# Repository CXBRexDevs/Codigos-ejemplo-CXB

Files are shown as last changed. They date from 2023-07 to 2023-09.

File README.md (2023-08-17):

# CXB Rex

Es una plataforma de desarrollo orientada hacia control avanzado de variables físicas, que integra drivers de motores, interfaces de comunicación y acoplo de sensores,  con el fin de facilitar experimentos para el desarrollo academico superior. En la siguiente [imagen](https://github.com/CXBRexDevs/Codigos-ejemplo-CXB/blob/015453cbffbb8909efc1b8809f53027d9adc56b4/images/BASEDibujoCXBareas.png) se aprecia la disposición de los periféricos disponibles al usuario. Mientras qeu las conexiones internas de la PCB se documentan en los [planos]() del proyecto.

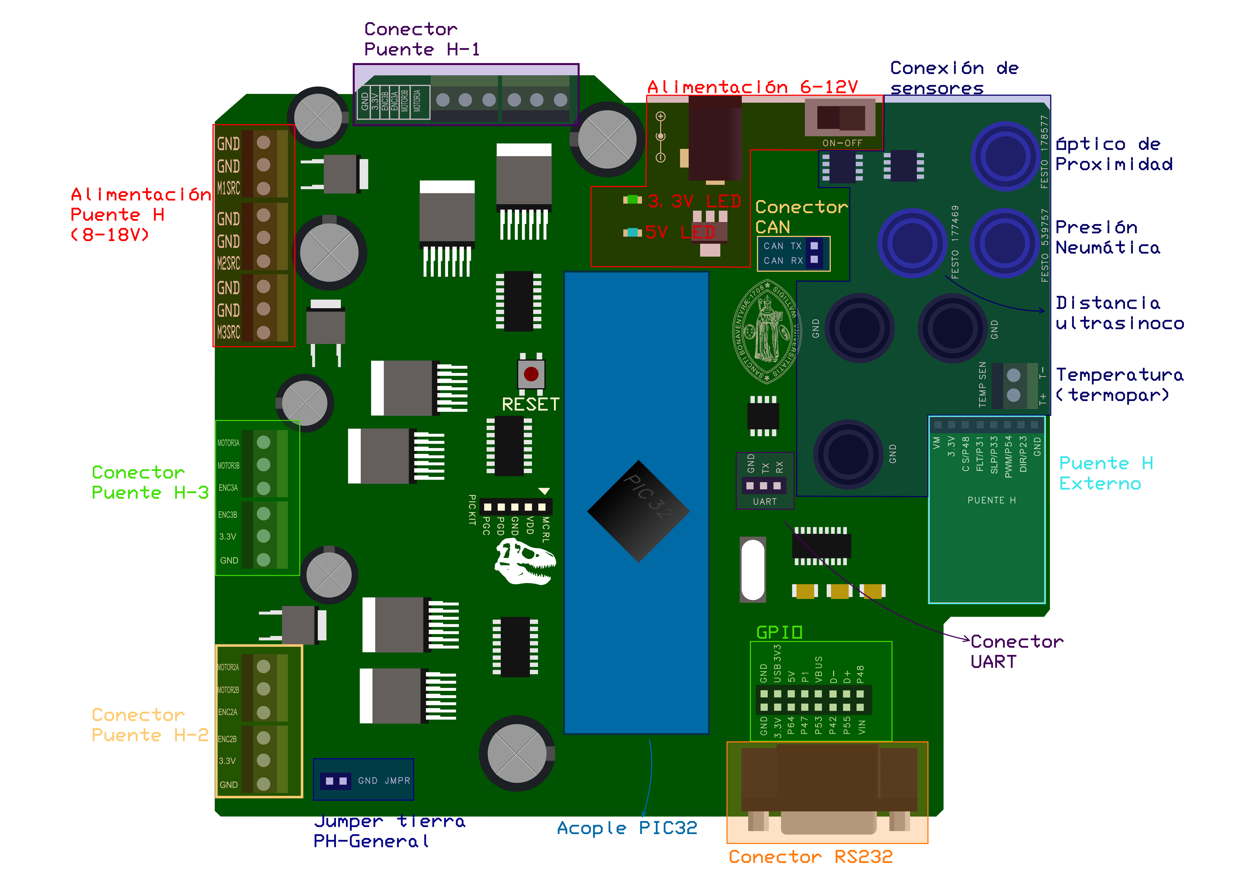
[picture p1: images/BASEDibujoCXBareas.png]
https://github.com/CXBRexDevs/Codigos-ejemplo-CXB/blob/main/images/BASEDibujoCXBareas.png?raw=true


En este repositorio se encuentran los planos y archivos de fabricación, códigos ejemplo, circuitos de prueba externos a la tarjeta electronica y entre otros archivos de interés.

# Guía de instalación programador

## *Advertencia: Pickit 3 solo es compatible con versiones de MPLAB anteriores a la versión 6.05*

## Programas necesarios

- MPLAB IDE

- Compilador XC32

- MPLAB Code Configurator
  
  ## MPLAB IDE
  
  Para la instalación de estos dos programas se debe ingresar a [MPLAB® X IDE | Microchip Technology](https://www.microchip.com/en-us/tools-resources/develop/mplab-x-ide) . Una vez en la página, seleccione la opción “Download MPLAB X IDE” y posteriormente descargue la versión de Windows.

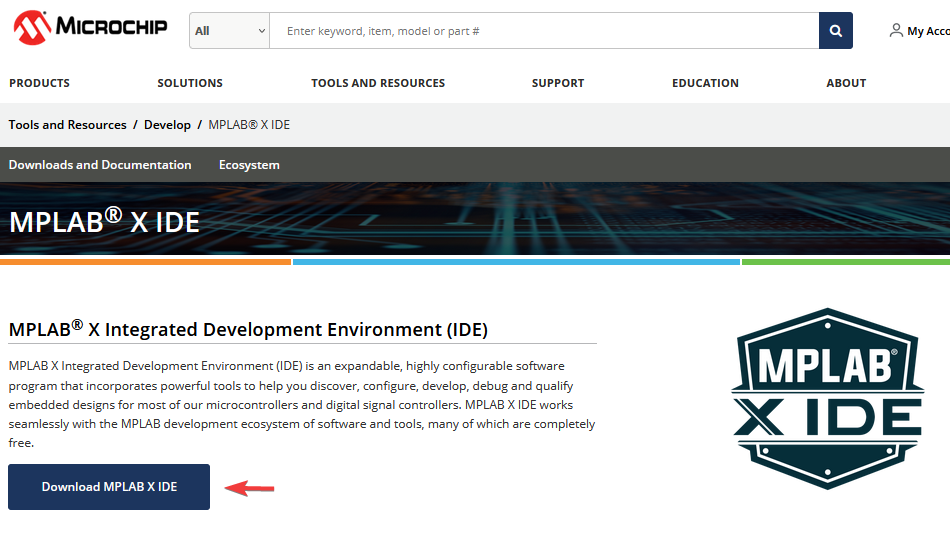
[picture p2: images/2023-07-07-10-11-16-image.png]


Puede descargar versiones anteriores navegando en la misma página al botón "Go To Downloads Archives" y buscando en el navegador su versión predilecta.

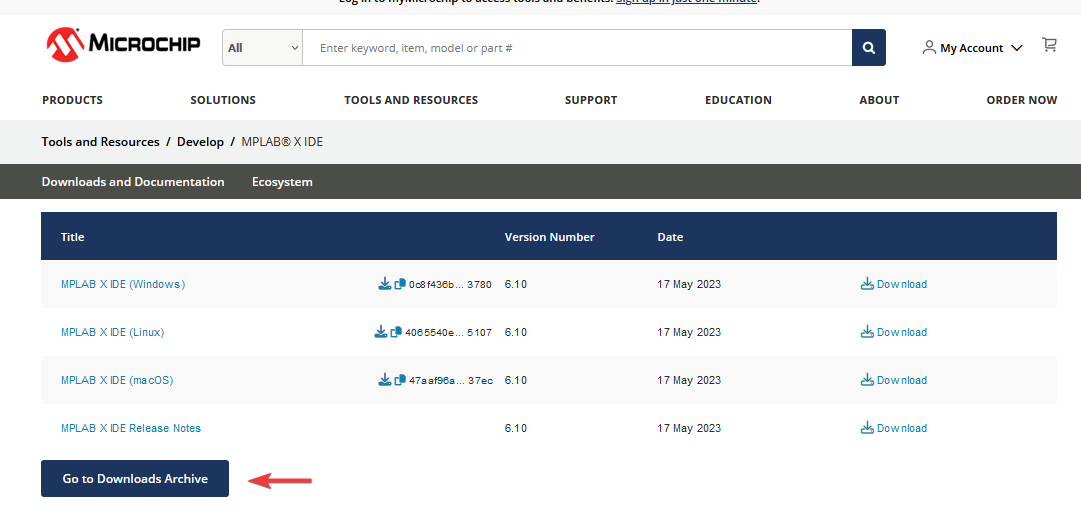
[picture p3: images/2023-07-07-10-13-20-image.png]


Una vez descargado el archivo abra el ejecutable.





Ahora debe dar clic en aceptar el acuerdo de usuario y así poder seguir el proceso de instalación haciendo clic en ‘next’.

![]([C:\Users\PEDRO\AppData\Roaming\marktext\images\2023-07-07-10-25-39-image.png](https://github.com/CXBRexDevs/Codigos-ejemplo-CXB/blob/main/images/2023-07-07-10-25-39-image.png?raw=true)https://github.com/CXBRexDevs/Codigos-ejemplo-CXB/blob/main/images/2023-07-07-10-25-39-image.png?raw=true)

Escoja el directorio donde desea instalar MPLAB X IDE y pulse siguiente.

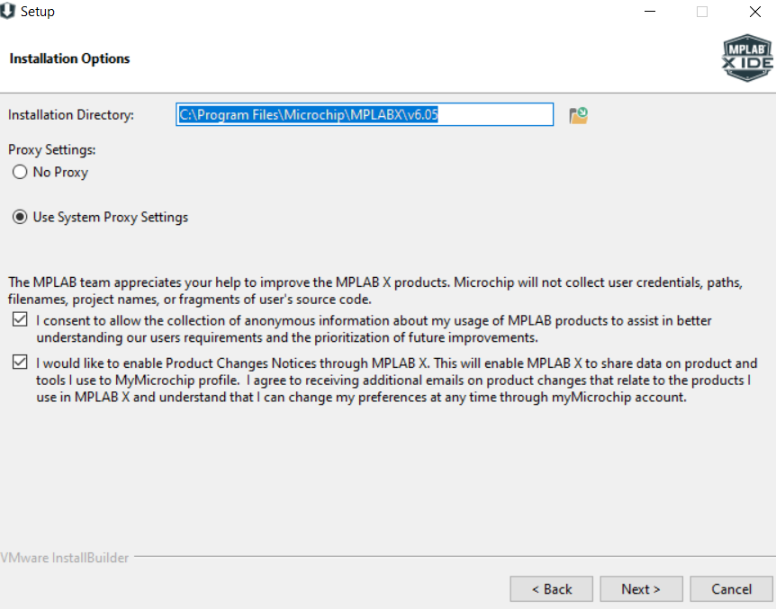
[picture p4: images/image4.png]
Modificar la ruta por defeco de instalación es opcional.


Ahora el instalador preguntará cuáles programas desea instalar, se recomienda la instalación de todos los aplicativos de la imagen abajo, pero para el uso de CXB-REX, solo es necesario “MPLAB X IDE” y “32 bit MCUs”.

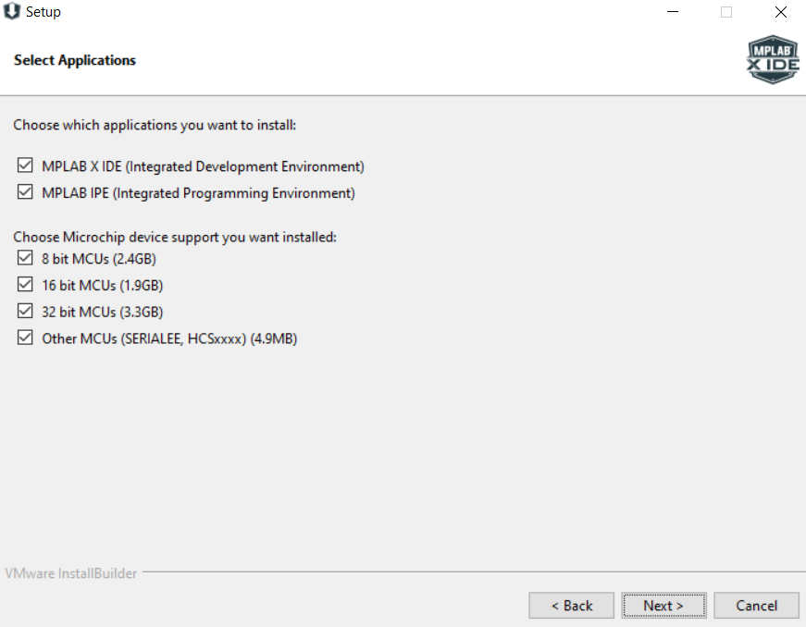
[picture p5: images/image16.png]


Al hacer clic en siguiente se iniciará la instalación.

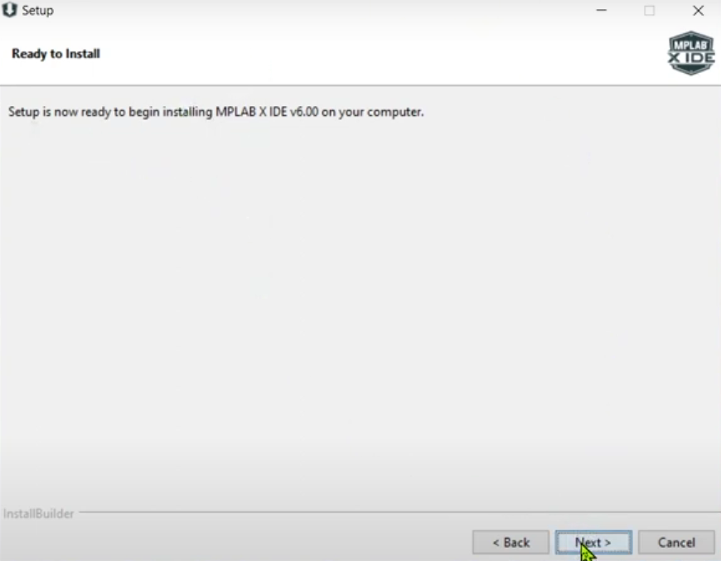
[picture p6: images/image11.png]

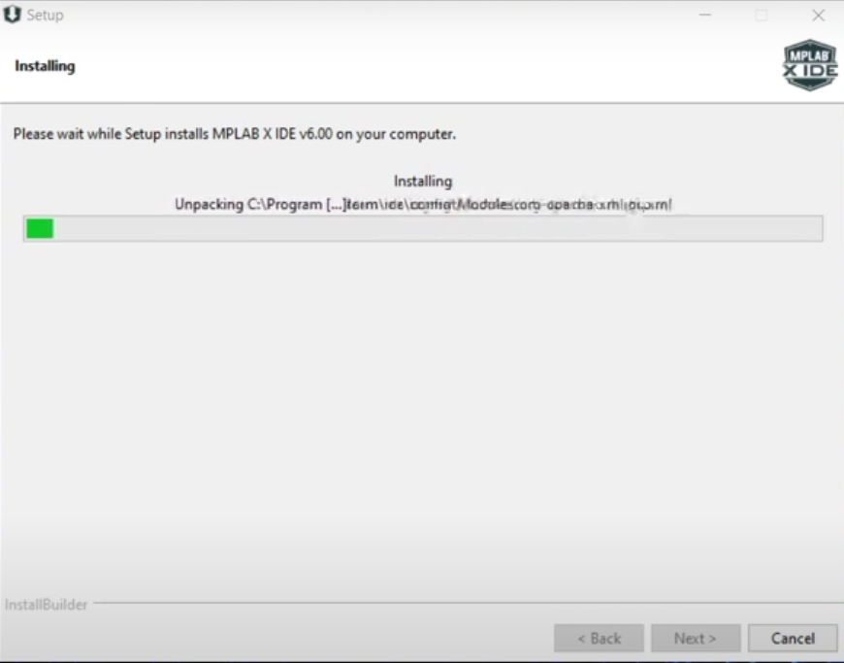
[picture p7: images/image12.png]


Espere a que termine la instalación y haga clic en finalizar una vez la opción se habilite.

## MPLAB XC32 COMPILER:

Ingrese a [MPLAB XC Compiler Downloads and Documentation | Microchip Technology](https://www.microchip.com/en-us/tools-resources/develop/mplab-xc-compilers/downloads-documentation) y seleccione la opción “XC32 Compilers” y posteriormente descargue la versión de Windows.

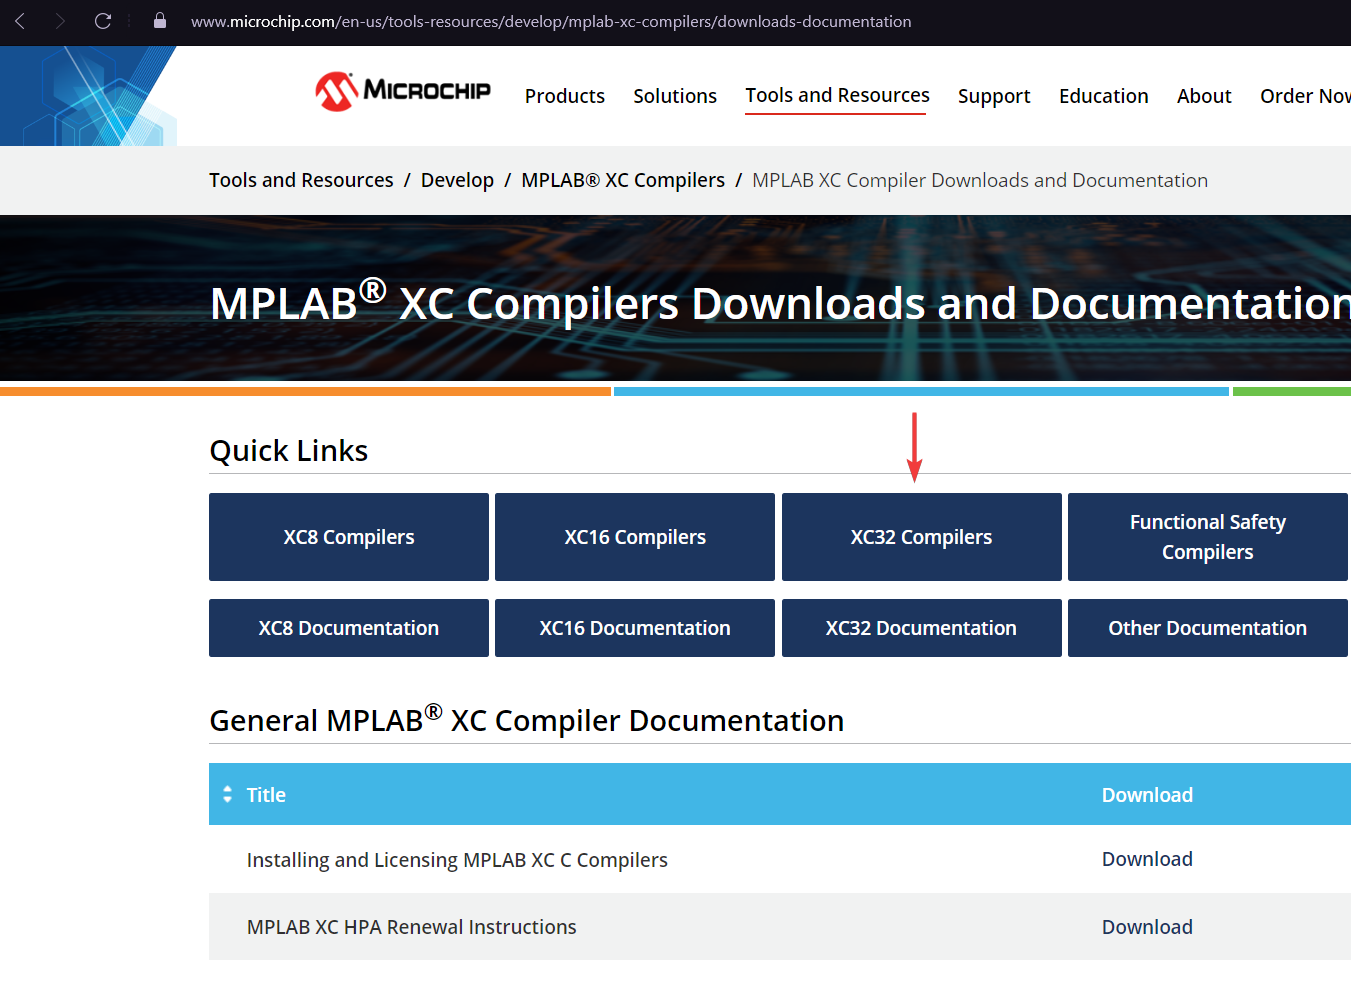
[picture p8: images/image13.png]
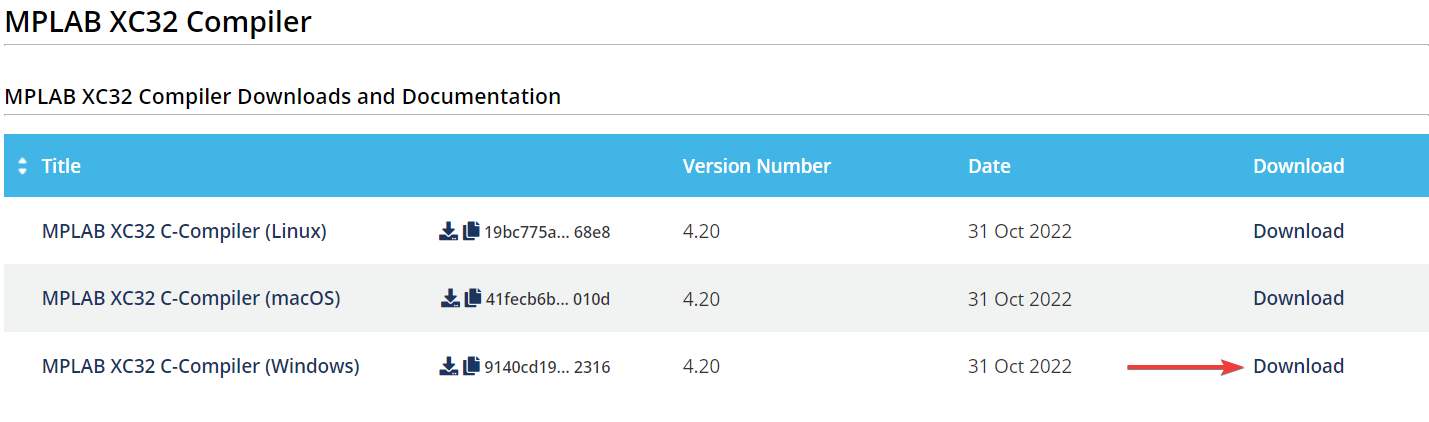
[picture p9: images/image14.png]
 

Una vez se ha descargado el instalador, ejecute la aplicación, los pasos a seguir son los mismos que para la instalación de MPLAB IDE, excepto por el tipo de licencia, en la cual debe seleccionar ‘free’.

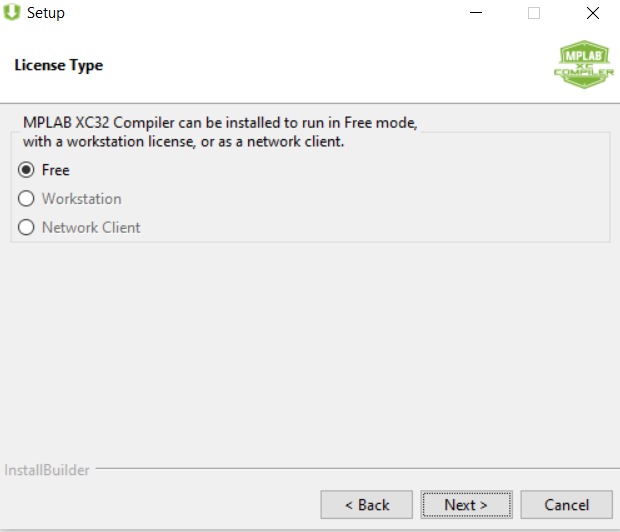
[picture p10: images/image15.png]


Después de escoger la licencia, se escoge el directorio de instalación y el programa procederá a instalarse, de la misma manera que MPLAB IDE, solo que al final dirá la información de la licencia, pero debido a que se seleccionó gratuita solo se debe dar clic en next para finalizar.

## MPLAB Harmony V3

El primer paso es abrir MPLAB IDE, luego seleccionar el apartado de "tools" en la parte superior de la pantalla, y en la ventana desplegada seleccionar "Plugins".

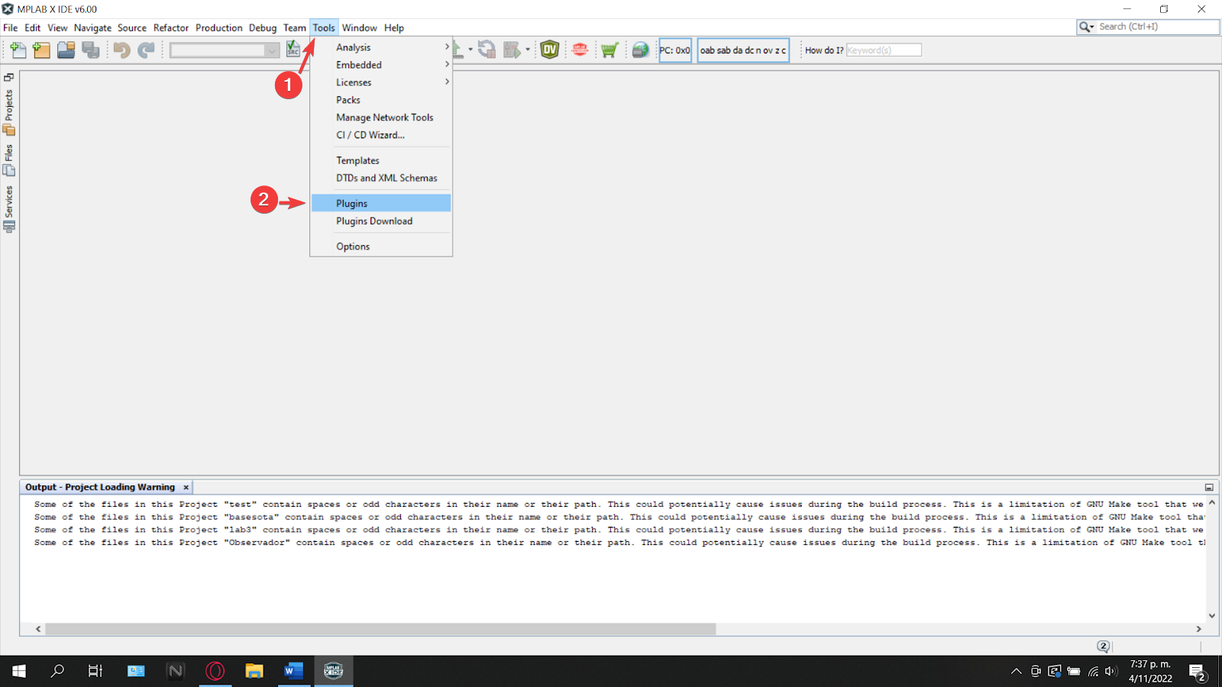
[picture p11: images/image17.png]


En la ventana de plugins seleccionar la pestaña de "Updates" y en el listado buscar si se encuentra “MPLAB@ Code Configurator”, si es el caso seleccionelo y haga clic en "Update".

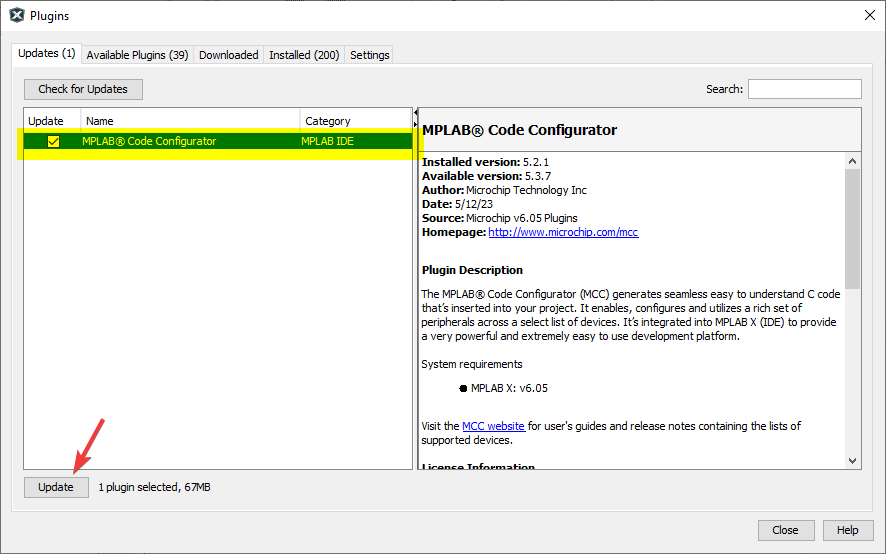
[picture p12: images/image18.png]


Aparecerá una nueva ventana dandole la bienvenida al instalador, haga clic en “Next” empezará la instalación.

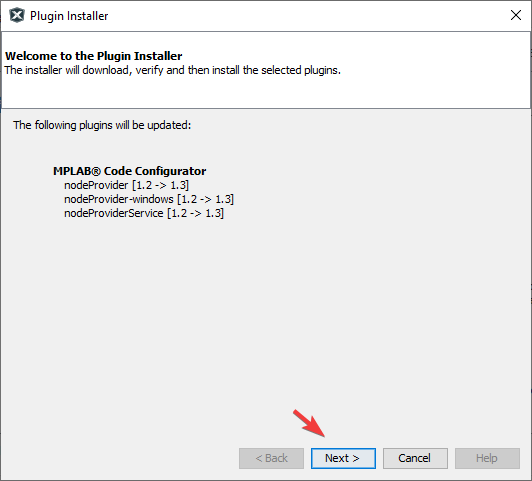
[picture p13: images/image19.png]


Luego de terminar aparecerá una ventana solicitando reiniciar MPLAB IDE para que los cambios tengan efecto, acepte y finalice.

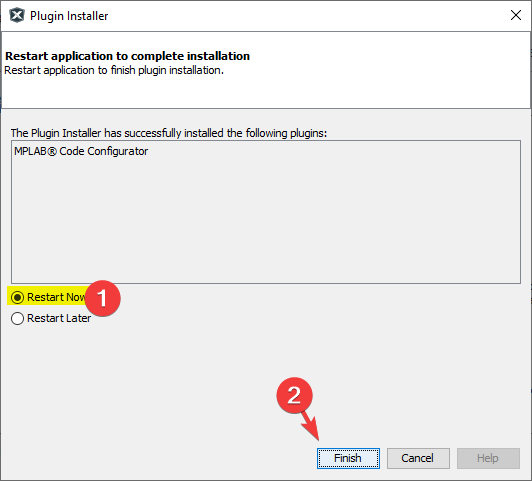
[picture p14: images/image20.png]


## Extensiones de Harmony 3:

Una vez se ha reiniciado MPLAB IDE con la instalación de harmony 3, seleccionamos en la pestaña Tools -> Embedded -> MPLAB Code Configurator v5 Open/Close

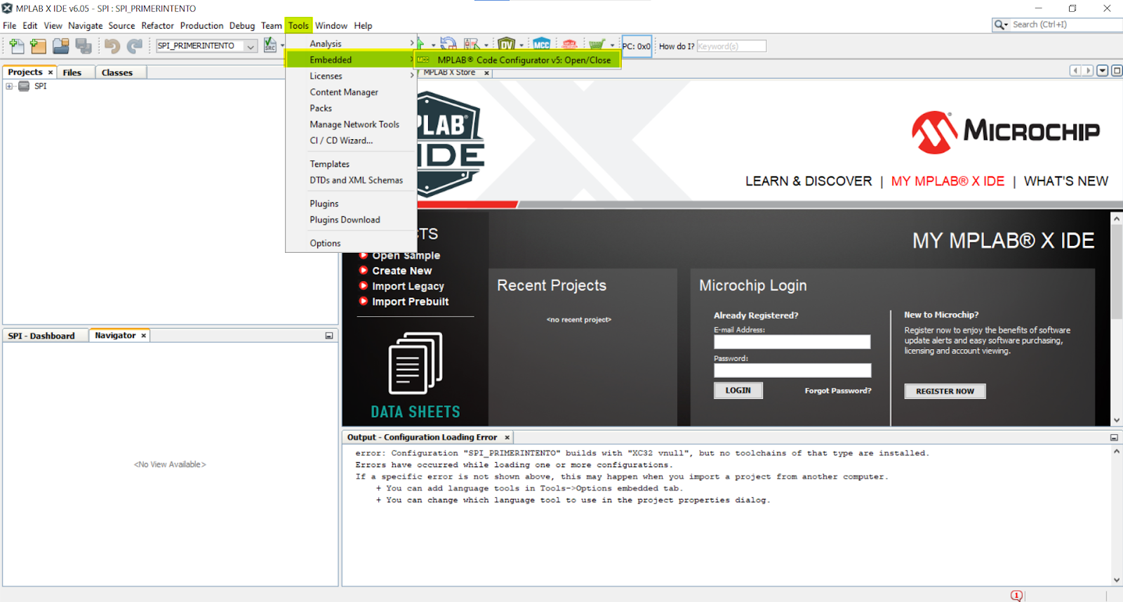
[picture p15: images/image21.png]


La primera vez que se inicia el programa mostrará un cuadro con el framework a elegir, en este caso se selecciona Harmony.

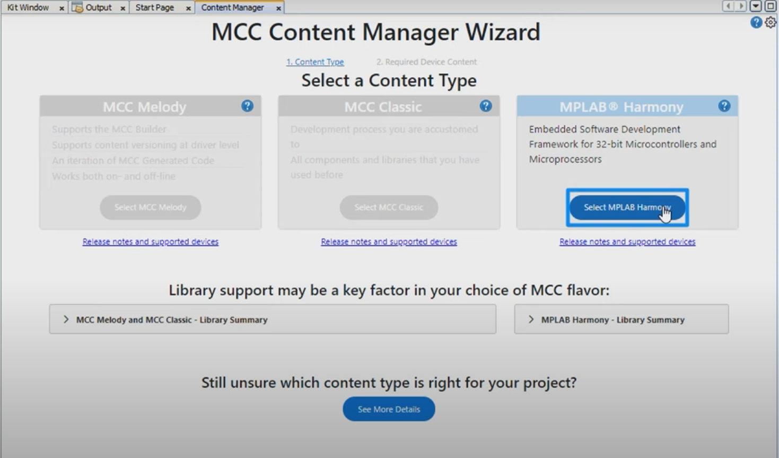
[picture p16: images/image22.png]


Una vez seleccionado aparecerá una tabla que indicara las extensiones requeridas.

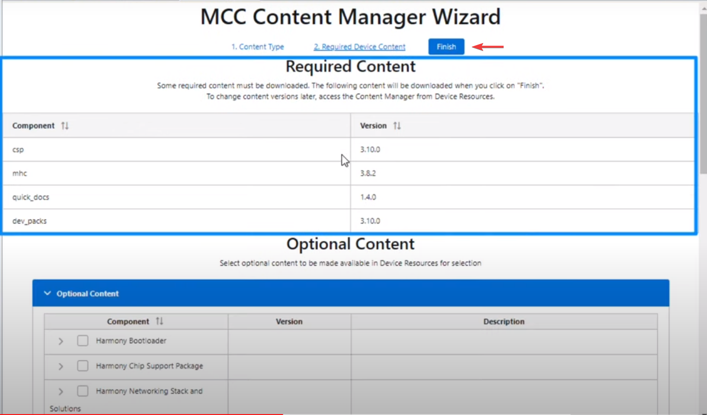
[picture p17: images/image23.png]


En caso de ser necesario también puede seleccionar las casillas del contenido opcional para que sean también se instale ese contenido, haga clic en "Finish" y espere, esto puede tomar unos minutos.  Se abrirá el siguiente entorno cuando haya terminado

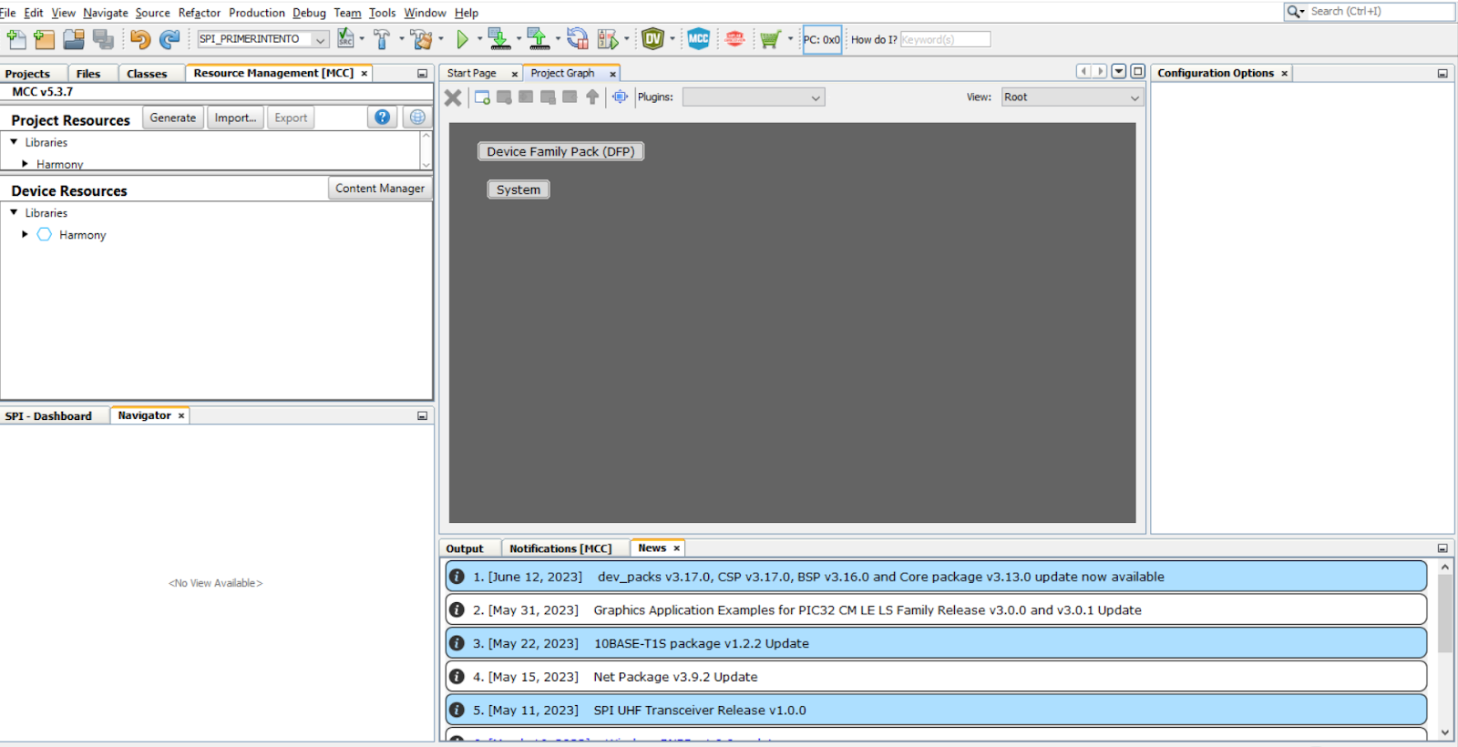
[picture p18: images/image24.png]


Ahora puede seguir la guía en "Mi primer proyecto", la cuál le guirá en este mismo proceso y le indicará como programar comunicación UART a USB o UART a RS232. También puede descargar este repositorio y abrir algún otro de los proyectos aquí descritos.

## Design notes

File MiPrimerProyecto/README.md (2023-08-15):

# Mi primer proyecto MCC HARMONY

Para empezar cualquier proyecto bajo la infraestructura de harmony v3 es necesario empezar por crear un proyecto, haga clic sobre la pestaña “File”, en la parte superior izquierda de la pantalla, luego haga clic en “New Project”. Una ventana nueva se desplegará. Seleccione la opción “32-bit MCC Harmony project”, luego pulse el botón “Next”. 

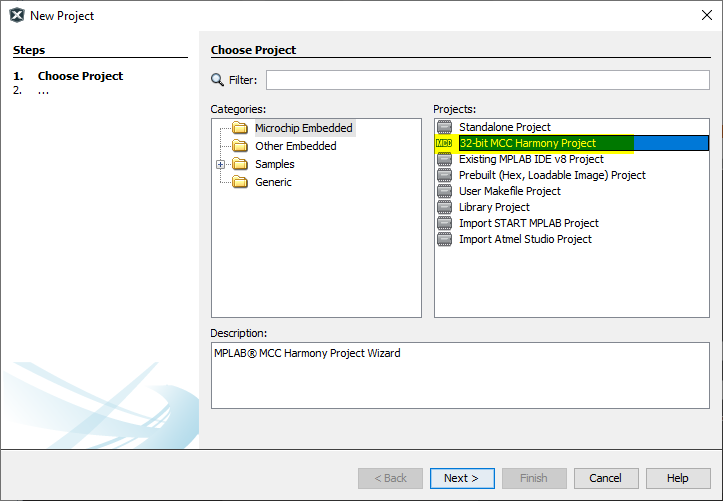
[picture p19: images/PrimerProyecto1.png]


Por defecto viene seleccionado el repositorio del cual se integra harmony 3 ([Microchip MPLAB Harmony GitHub](https://github.com/Microchip-MPLAB-Harmony/)) y la ruta donde se instalará para este proyecto (C:\Users\USUARIO\.mcc\HarmonyContent). No es necesario cambiar estas rutas, pulse el botón “Next”.

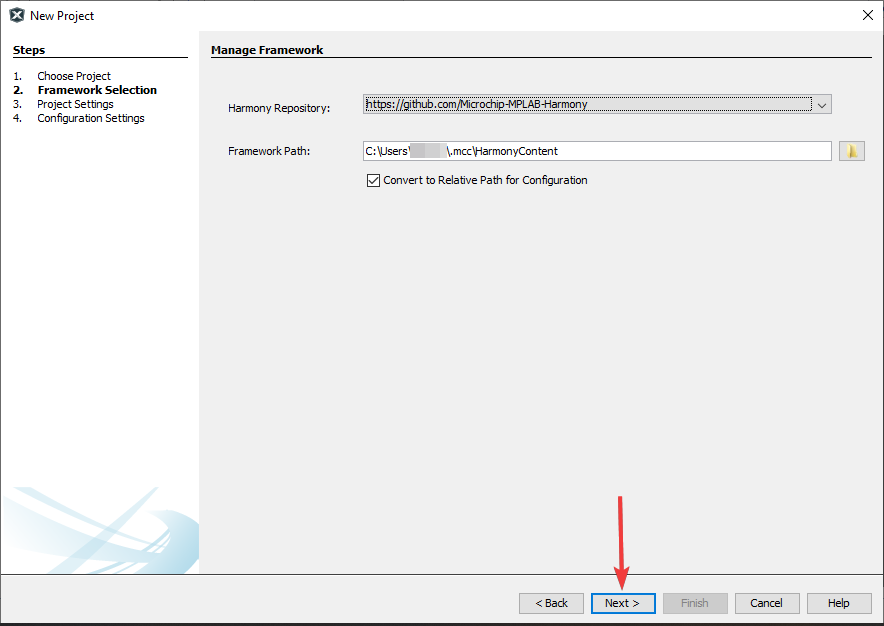
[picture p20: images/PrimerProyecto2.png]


El siguiente paso es escoger la ruta en la que se guardará su proyecto y definir su nombre, para este ejemplo, cambiaremos el nombre por defecto de la ruta a “MiPrimerProyecto” (1) y el nombre del proyecto a “HolaMundo” (2).

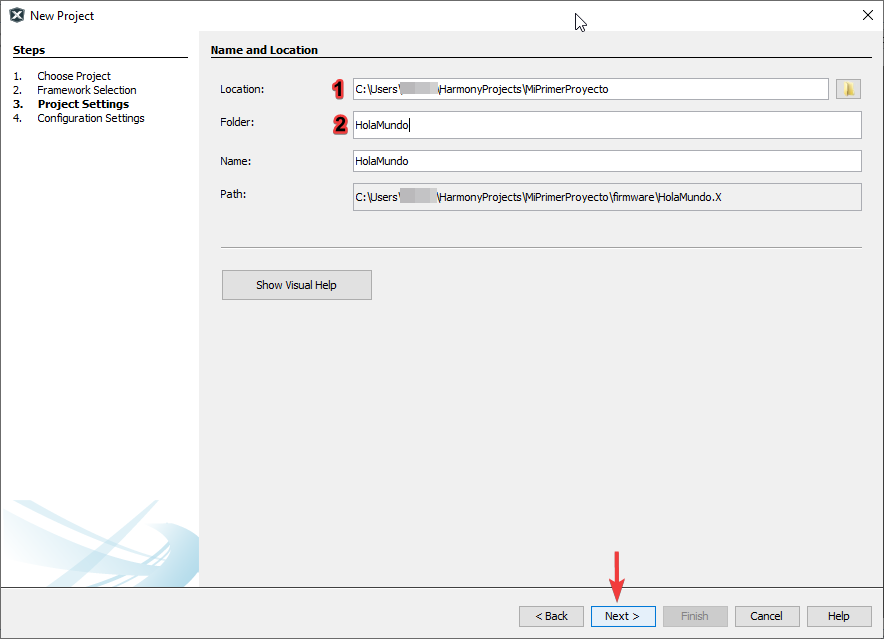
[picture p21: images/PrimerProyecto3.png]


Asegúrese de seleccionar el pic instalado en su tarjeta, CXB Rex es compatible con la familia de microcontroladores PIC32MKxxxxMCF064. En este ejemplo se selecciona PIC32MK1024MCF04.

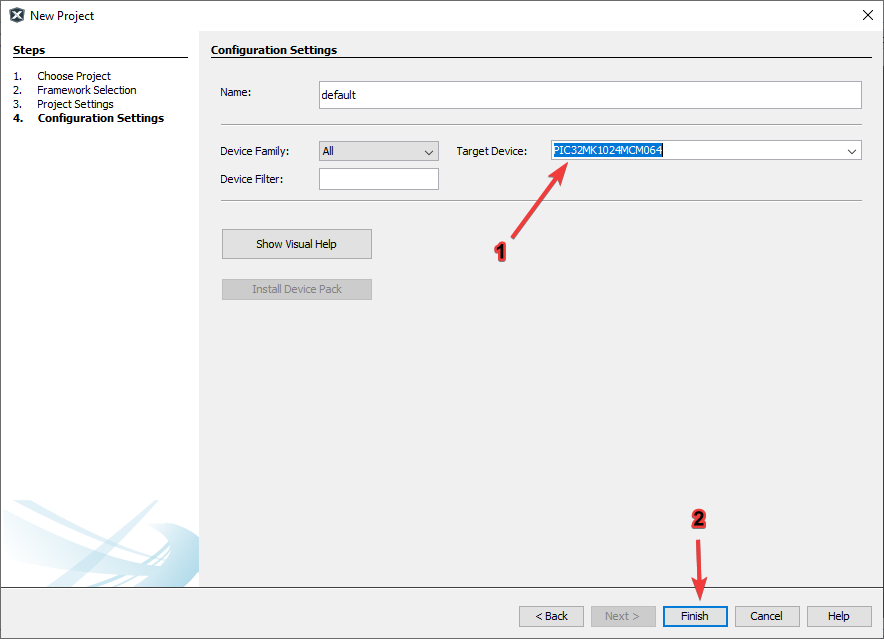
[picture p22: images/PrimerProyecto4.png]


Haga clic en “Finish” para terminar el proceso de creación del proyecto.

## Entorno

Una vez creado su proyecto, inicie MCC haciendo clic en el icono “Mplab Code Configurator” para iniciar la configuración. Una vez haya abierto el entorno de configuración usted verá 3 áreas diferentes.

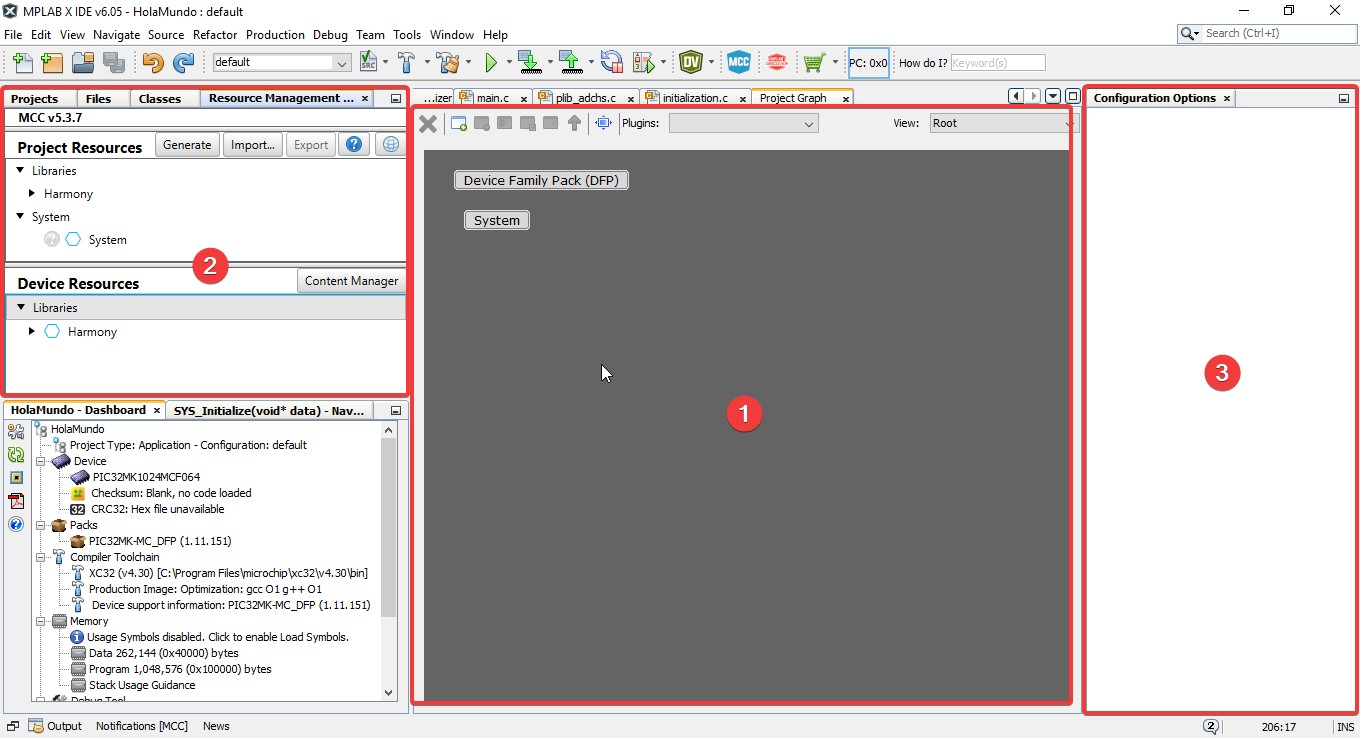
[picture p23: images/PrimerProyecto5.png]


1. **Área de composición:** En esta área usted podrá visualizar las diversas configuraciones disponibles a una macro escala, esto incluye periféricos, interconexiones que existen entre ellos, configuración de pines, de reloj, entre otros.

2. **Área de recursos:** En esta área se presentan los periféricos, en “Device Reourses” se encuentran los que podrá agregar a su proyecto y en “Project Resourses” se ubican los recursos y periféricos ya agregados.

3. **Área de configuración:** Aquí se mostrarán, al seleccionar un periférico en el área de composición y las configuraciones específicas de ese periférico.

## Comunicación serial (Hola Mundo)

Para este proyecto usted necesitará:

- Conversor de UART a USB y/o conversor RS232 a USB. 

- Protoboard.

- 2 diodos emisores de luz.

- 2 resistencias de 330 Ω.

- 1 resistencia de 1k Ω.

- Instalar un terminal de puerto serial, por ejemplo RealTerm (en Windows) o CuteCom (en Mac Os o Linux).

Empezaremos por crear un proyecto básico en el que se demuestra el uso de las áreas de MCC, este proyecto enviará un mensaje a través del puerto UART de la tarjeta y le permitirá encender un LED. Empiece por desplegar el menú “Harmony” en “Device Resources” visto en el área de recursos, luego despliegue “Peripherals”, busque la opción UART y escoja el periférico “UART5” haciendo clic en la cruz verde.

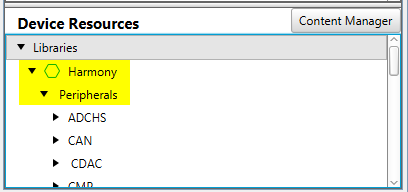
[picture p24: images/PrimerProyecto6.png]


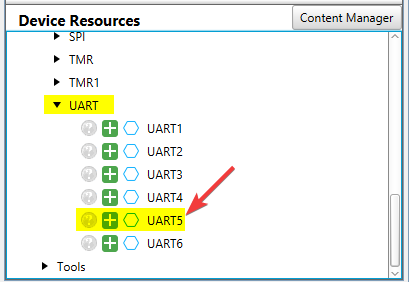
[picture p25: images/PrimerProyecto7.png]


Aparecerá una caja gris en el área de composición, al hacer clic sobre cualquiera de los cajones en este espacio, este se verá seleccionado, se indica con el recuadro verde a su alrededor. Los ítems seleccionados tienen sus propiedades expuestas en el área de configuración.

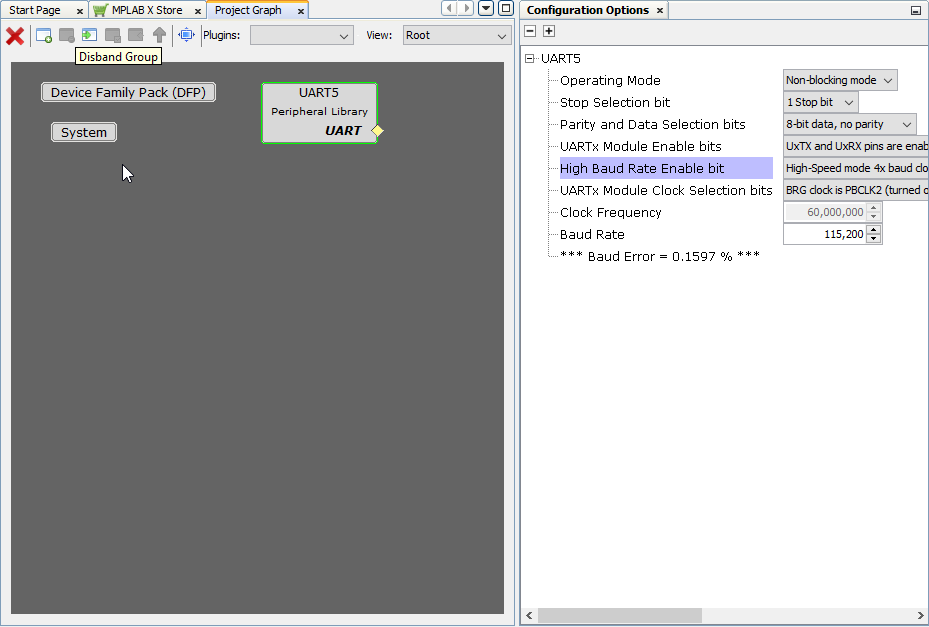
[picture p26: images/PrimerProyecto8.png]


Despliegue el menú “Tools” en el área de recursos y agregue también el periférico STDIO, que significa "*S*tandard *I*nput-*O*utput *H*eader", este permitirá hacer operaciones estándar a través de los pines, conecte los diamantes de UART5 y STDIO. Agregue también el periférico “Core Timer”.

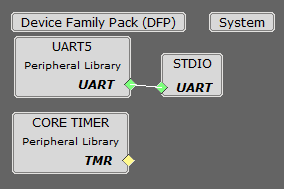
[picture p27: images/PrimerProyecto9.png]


Seleccione UART5 y configure de la siguiente forma.

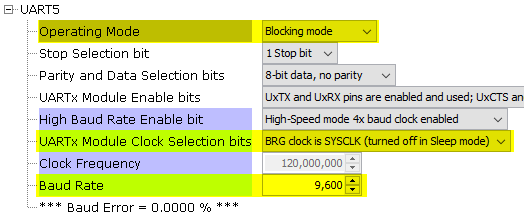
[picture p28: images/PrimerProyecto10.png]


No es necesario hacer configuraciones extra en los demás periféricos.

Despliegue el menú “plugins” visto en la parte superior del área de composición y seleccione la opción “pin configuration”.

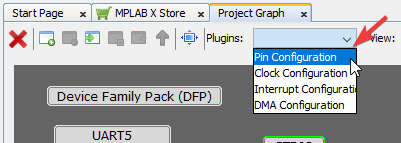
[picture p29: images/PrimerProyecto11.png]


Se abrirán 3 pestañas en el área de configuración, las tres son una representación gráfica diferente de la configuración de pines, su función y sus nombres.

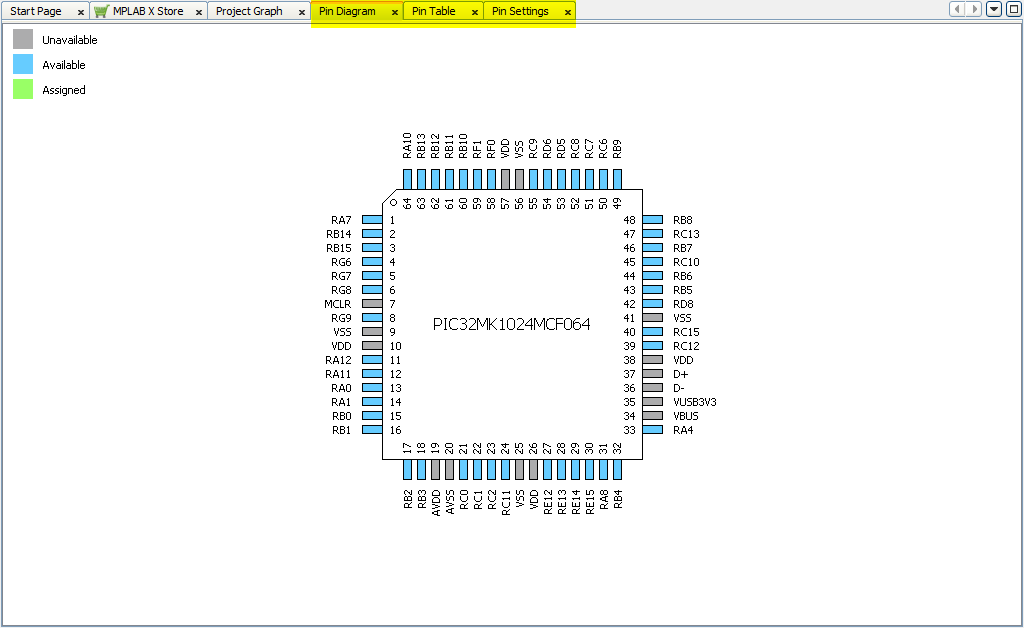
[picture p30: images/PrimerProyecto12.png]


Usted puede escoger la configuración de los pines desde la pestaña de su preferencia, pero para nuestros fines usaremos la pestaña “pin settings”. Busque el pin 23, haga clic en el desplegable visto en la columna “Function” y seleccione la opción GPIO, para hallarla más fácilmente puede pulsar la letra “G” en su teclado, acto seguido nombre el pin haciendo doble clic en la casilla correspondiente sobre la columna “Custom Name” e ingrese el nombre “LED1”, luego, en la columna “Direction (TRIS)”, escoja “Out” y en la columna “Latch (LAT)” escoja “Low”. Repita este proceso en los pines 33 y 54, cambiando el nombre de los pines a “PULSE1” y “LED0” respectivamente, cambié la dirección de “PULSE1” a “In”.





Luego busque los pines 44 y 49, haga clic sobre los desplegables en la columna “Function” y seleccione “U5RX” y “U5TX” respectivamente, nómbrelos “UARTRX” y “UARTTX”. La configuración debe quedar de la siguiente forma.

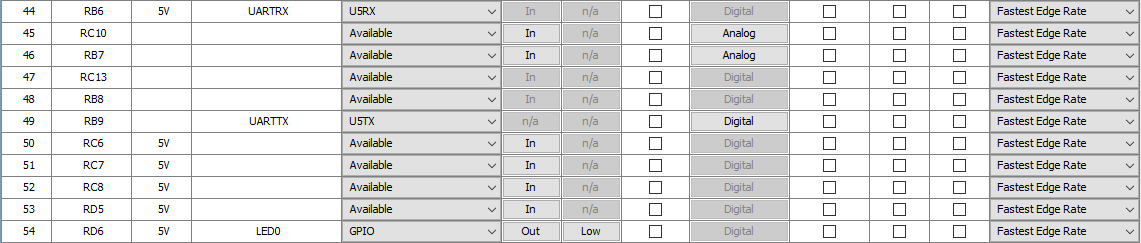
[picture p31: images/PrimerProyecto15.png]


Esto se corresponderá con las otras pestañas, puede visualizar la implementación de estos pines en la pestaña “Pin Diagram”.

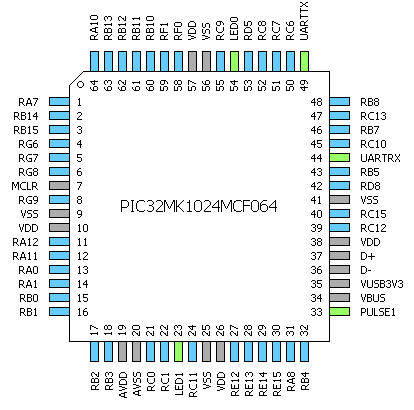
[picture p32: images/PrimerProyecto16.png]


Genere la configuración de su proyecto haciendo clic en el botón “Generate” en el área de recursos y espere a que MCC termine el proceso.

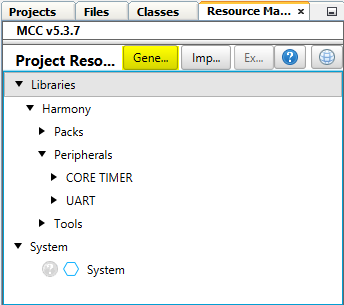
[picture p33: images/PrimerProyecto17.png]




Una vez haya terminado podrá regresar a la pestaña “Projects”, en el área de recursos, y navegar en los archivos del proyecto, MCC habrá generado los archivos de cabecera (header), de extensión .h, archivos de configuración (config-default) y principal (main) de extensión .c estos archivos contienen las funciones de los periféricos configurados y facilitarán la programación de su microcontrolador.

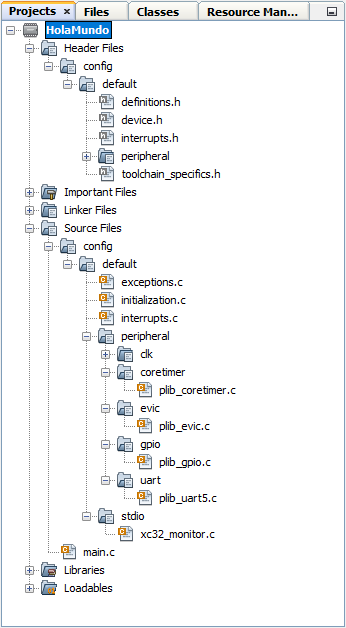
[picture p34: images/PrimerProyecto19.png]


Abra el archivo “main.c” haciendo doble clic en él, luego pegue el siguiente código:

```c
#include <stddef.h>            	// Defines NULL
#include <stdbool.h>           	// Defines true
#include <stdlib.h>            	// Defines EXIT_FAILURE
#include "definitions.h"    	// SYS function prototypes

/* Define a dentro del buffer el mensaje que se enviará por
medio del UART5*/
	unsigned char buffer[]=;
int main ( void )
{
	SYS_Initialize ( NULL );
	while ( true )
	{
	if(PULSE1_Get()){ //Si el valor de PULSE1 es verdadero
        	LED1_Set(); // Encienda LED1
        	LED0_Clear(); // Apague LED0
        	CORETIMER_DelayMs (500); // Espere 0.5 segundos
    	}
    	else{
        	LED0_Set(); // Encienda LED0
        	LED1_Clear(); // Apague LED1
    	}
	
/*Escriba el mensaje en el puerto UART*/
printf("Hola mundo \n");
    	SYS_Tasks ( );
	}
	return ( EXIT_FAILURE );
}

```
Conecte su conversor TTL a USB como se muestra en la siguiente [figura](https://github.com/CXBRexDevs/Codigos-ejemplo-CXB/blob/main/images/CXBUART.png?raw=true), luego conecte este a su PC, conecte la alimentación de la tarjeta y energicela encendiendo el switch, los LEDs testigos de 3.3V y 5V se encenderán. Programe su microcontrolador.

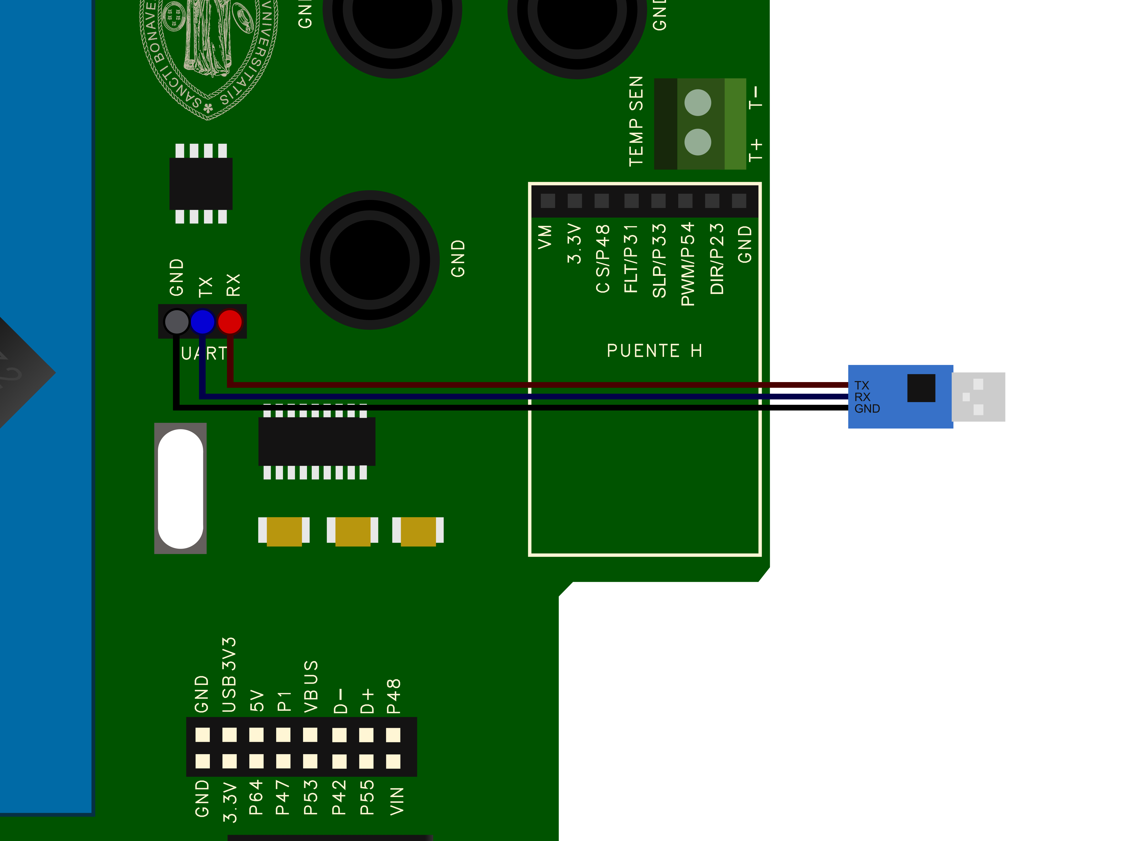
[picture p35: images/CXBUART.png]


Una vez haya programado abra el terminal serial predilecto (Ejemplo: realTerm) y configure el puerto serial igual que como se programó previemente el canal UART y abra el terminal, debería ver el mensaje ```Hola mundo``` reescribiendoce constantemente.

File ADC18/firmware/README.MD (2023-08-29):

# Configuración de registros

A pesar de ser muy útil en la mayoría de proyectos, la configuración con MCC harmony para los puertos ADCHS han presentado lo que presumiblemente sean bugs, así que se recomienda hacer una configuración manual del archivo "[plib_adchs.c](https://github.com/CXBRexDevs/Codigos-ejemplo-CXB/blob/main/ADC18/firmware/src/config/default/peripheral/adchs/plib_adchs.c)" para este ejemplo, la configuración de registros se encuentra a continuación y fue adaptada del ejemplo provisto en él [manual para puertos ADC para pic32](https://ww1.microchip.com/downloads/en/DeviceDoc/Section22._12-bit_HS_SAR_ADC_FRM_DS60001344E.pdf), el cual cuenta con algunos errores de tipografía, los cuales fueron corregidos en este repositorio.

```C
void ADCHS_Initialize(void)
{
    /* Configure ADCCON1 */
    ADCCON1bits.FRACT = 1; // use Fractional output format
    ADCCON1bits.SELRES = 3; // ADC7 resolution is 12 bits
    ADCCON1bits.STRGSRC = 0; // No scan trigger.
    /* Configure ADCCON2 */
    ADCCON2bits.SAMC = 6; // ADC7 sampling time = 5 * TAD7
    ADCCON2bits.ADCDIV = 1; // ADC7 clock freq is half of control clock = TAD7
    /* Initialize warm up time register */
    ADCANCON = 0;
    ADCANCONbits.WKUPCLKCNT = 5; // Wakeup exponent = 32 * TADx
    /* Clock setting */
    ADCCON3 = 0;
    ADCCON3bits.ADCSEL = 0; // Select input clock source
    ADCCON3bits.CONCLKDIV = 1; // Control clock frequency is half of input clock
    ADCCON3bits.VREFSEL = 0; // Select AVDD and AVSS as reference source
    /* No selection for dedicated ADC modules, no presync trigger, not sync sampling */
    ADCTRGMODE = 0;
    /* Select ADC input mode */
    ADCIMCON2bits.SIGN17 = 0; // unsigned data format
    ADCIMCON2bits.DIFF17 = 0; // Single ended mode
    ADCIMCON2bits.SIGN18 = 0; // unsigned data format
    ADCIMCON2bits.DIFF18 = 0; // Single ended mode
    ADCIMCON2bits.SIGN19 = 0; // unsigned data format
    ADCIMCON2bits.DIFF19 = 0; // Single ended mode
    /* Configure ADCGIRQENx */
    ADCGIRQEN1 = 0; // No interrupts are used
    ADCGIRQEN2 = 0;
    /* Configure ADCCSSx */
    ADCCSS1 = 0; // No scanning is used
    ADCCSS2 = 0;
    /* Configure ADCCMPCONx */
    ADCCMPCON1 = 0; // No digital comparators are used. Setting the ADCCMPCONx
    ADCCMPCON2 = 0; // register to '0' ensures that the comparator is disabled.
    ADCCMPCON3 = 0; // Other registers are ?don't care?.
    ADCCMPCON4 = 0;

    /* Configure ADCFLTRx */
    ADCFLTR1 = 0; // No oversampling filters are used.
    ADCFLTR2 = 0;
    ADCFLTR3 = 0;
    ADCFLTR4 = 0;

    /* Set up the trigger sources */
    ADCTRGSNSbits.LVL17 = 0; // Edge trigger
    ADCTRGSNSbits.LVL18 = 0; // Edge trigger
    ADCTRGSNSbits.LVL19 = 0; // Edge trigger
    ADCTRG5bits.TRGSRC17 = 1; // Set AN17 to trigger from software
    ADCTRG5bits.TRGSRC18 = 1; // Set AN18 to trigger from software
    ADCTRG5bits.TRGSRC19 = 1; // Set AN19 to trigger from software

    /* Early interrupt */
    ADCEIEN1 = 0; // No early interrupt
    ADCEIEN2 = 0;
    /* Turn the ADC on */
    ADCCON1bits.ON = 1;

    /* Turn ON ADC */
    ADCCON1bits.ON = 1;
    while(ADCCON2bits.BGVRRDY == 0U) // Wait until the reference voltage is ready
    {

    }
    while(ADCCON2bits.REFFLT != 0U) // Wait if there is a fault with the reference voltage
    {

    }

    /* ADC 7 */
    ADCANCONbits.ANEN7 = 1;      // Enable the clock to analog bias
    while(ADCANCONbits.WKRDY7 == 0U) // Wait until ADC is ready
    {

    }
    ADCCON3bits.DIGEN7 = 1;      // Enable ADC

}
```

> **NOTA: Configuración ejemplo adaptada de [Section 22. 12-bit High-Speed Successive Approximation
> Register (SAR) Analog-to-Digital Converter (ADC)](https://ww1.microchip.com/downloads/en/DeviceDoc/Section22._12-bit_HS_SAR_ADC_FRM_DS60001344E.pdf) (página 70)**

Configure los pines que se usan para los terminales banana como ANx (x: El número del canal ADC correspondiente al pin), es decir: "[FESTO 177469](https://ip.festo-didactic.com/InfoPortal/DataSheets/INT/177469_en_v2.0_Analog_ultrasonic_distance_sensor.pdf)" &rarr; AN19 (Pin 4) "[FESTO 539757](https://ip.festo-didactic.com/InfoPortal/DataSheets/INT/539757_es_v2.0_Sensor_de_presi%C3%B3n_SDE1.pdf)" &rarr; AN18 (Pin 5) y "[FESTO 178577](https://ip.festo-didactic.com/InfoPortal/DataSheets/INT/178577_en_v2.0_Proximity_sensor_optical.pdf)" &rarr; AN17 (Pin 6). Invoque en el área de composición los bloques ADCHS, UART5 y STDIO configure estos últimos dos como se hizo en [MiPrimerProyecto](https://github.com/CXBRexDevs/Codigos-ejemplo-CXB/tree/main/MiPrimerProyecto), sin hacer modificaciones a los registros del bloque ADCHS genere la configuración y reemplace la función ```ADCHS_Initialize()``` con la configuración provista en el bloque de código visto más arriba, el proyecto ejemplo provisto en este repositorio ya cuenta con los cambios que acaba de leer.

# Hardware

Conecte el módulo UART a USB, como se ilustra en la siguiente imagen.



> A continuación se presenta un listado indicando las conexiones que se observan en la imagen superior.

> + ***Cable Azul:*** Transmisión (UART CXB_REX) → Recepción (UART MÓDULO EXTERNO)
> + ***Cable Rojo:*** Recepción (UART CXB_REX) → Transmisión (UART MÓDULO EXTERNO)
> + ***Cable Negro:*** GND (UART CXB_REX) → GND (UART MÓDULO EXTERNO)

Conecte los cables de los sensores mencionados a sus respectivos puertos, incluyendo la tierra de los sensores, conecte la alimentación de los sensores a la fuente de PLC y asegúrece de puentear la tierra de la fuente con la tierra del circuito, **tenga cuidado de conectar los sensores a su respectivo puerto y no los intercambie**. Los circuitos internos de CXB correspondientes al acople de las señales de los sensores se ilustran a continuación.

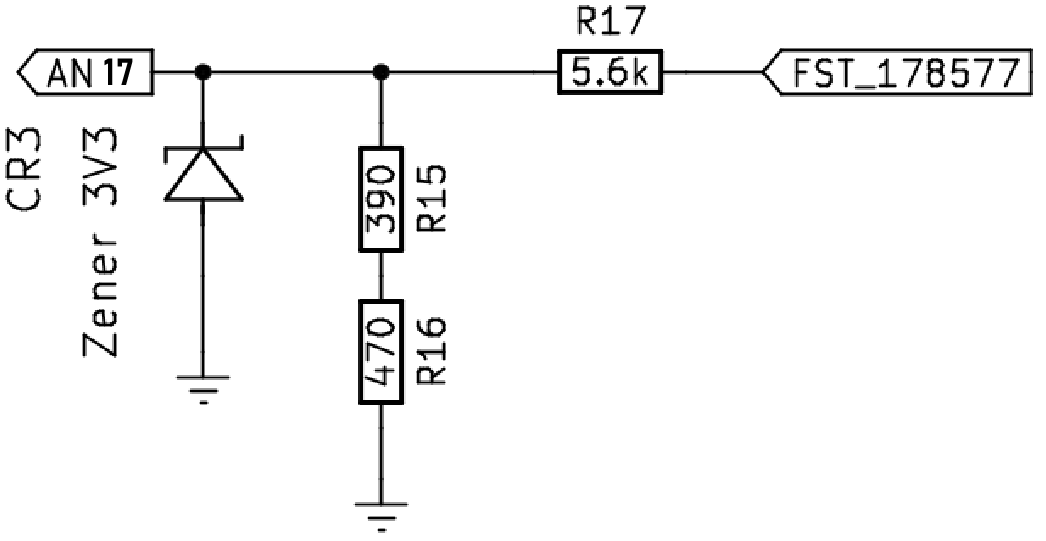
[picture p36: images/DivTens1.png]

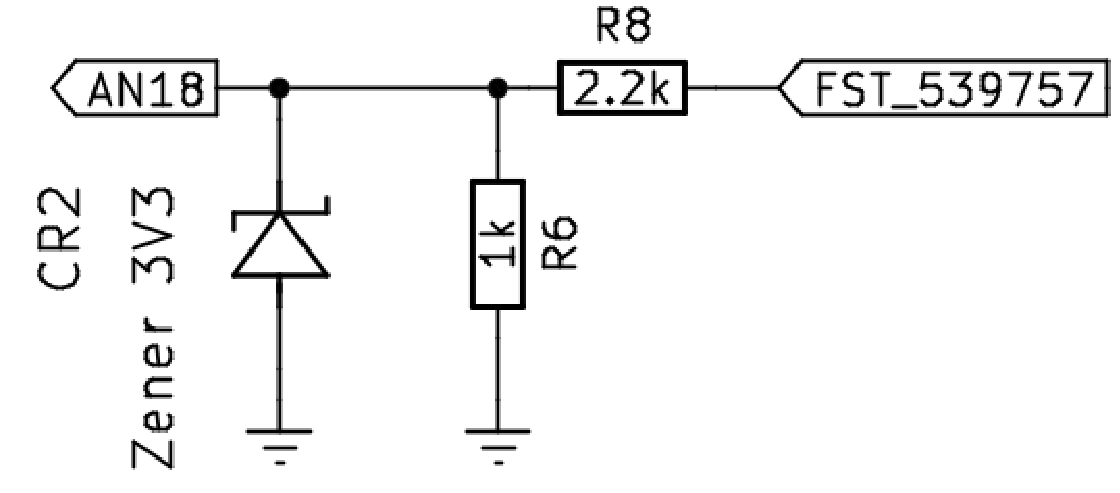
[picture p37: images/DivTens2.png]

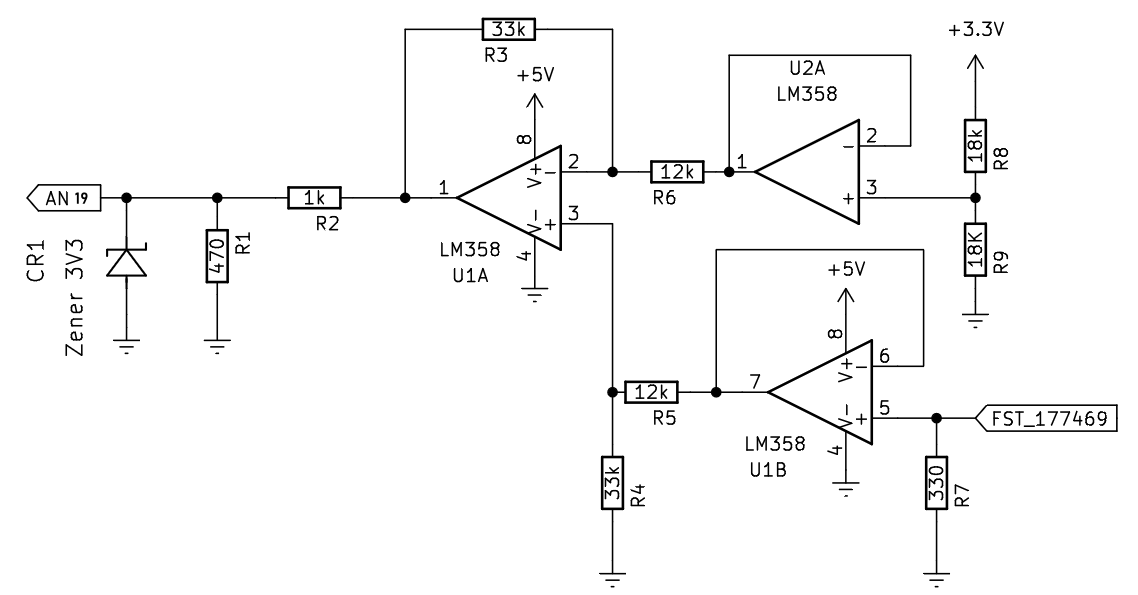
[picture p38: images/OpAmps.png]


Para mayor información sobre el módulo ADC en dispositivos PIC32 puede leer [Microchip Analog-to-Digital Converter (ADC) with Threshold Detect](https://ww1.microchip.com/downloads/en/DeviceDoc/60001359b.pdf), [Section 22. 12-bit High-Speed Successive Approximation
Register (SAR) Analog-to-Digital Converter (ADC)](https://ww1.microchip.com/downloads/en/DeviceDoc/Section22._12-bit_HS_SAR_ADC_FRM_DS60001344E.pdf) y el capítulo designado a ADC en el datasheet de su microcontrolador, por ejemplo [PIC32MK1024MCF064](https://ww1.microchip.com/downloads/en/DeviceDoc/PIC32MK_GP_MC_Familly_Datasheet_60001402G.pdf#G26.1079552).

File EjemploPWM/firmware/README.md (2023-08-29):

# Software
Este código utiliza el módulo PWM número 1, el periodo se configuró por medio de los registros del PWM de la familia del microcontrolador PIC32.

```C
#define PERIODO_PWM      1000  // periodo del PWM
#define PORCENT          1     // ciclo útil del PWM

int main(void)
{
    MCPWM_Initialize();     // Inicializa el módulo PWM
    MCPWM_Start();          // Inicializa el funcionamiento del PWM  
    
    MCPWM_ChannelPrimaryDutySet(MCPWM_CH_1, PERIODO_PWM * 1); // Establece un ciclo útil en el canal 1
```

En el espacio superior se puede apreciar una fracción del código "[main.c](https://github.com/CXBRexDevs/Codigos-ejemplo-CXB/blob/main/EjemploPWM/firmware/src/main.c)" del ejemplo del PWM donde en las primeras líneas se pueden modificar el periodo del PWM y el ciclo útil respectivamente, más abajo se puede ver la inicialización del PWM al igual que la función que establece el periodo de PWM en el canal primario.

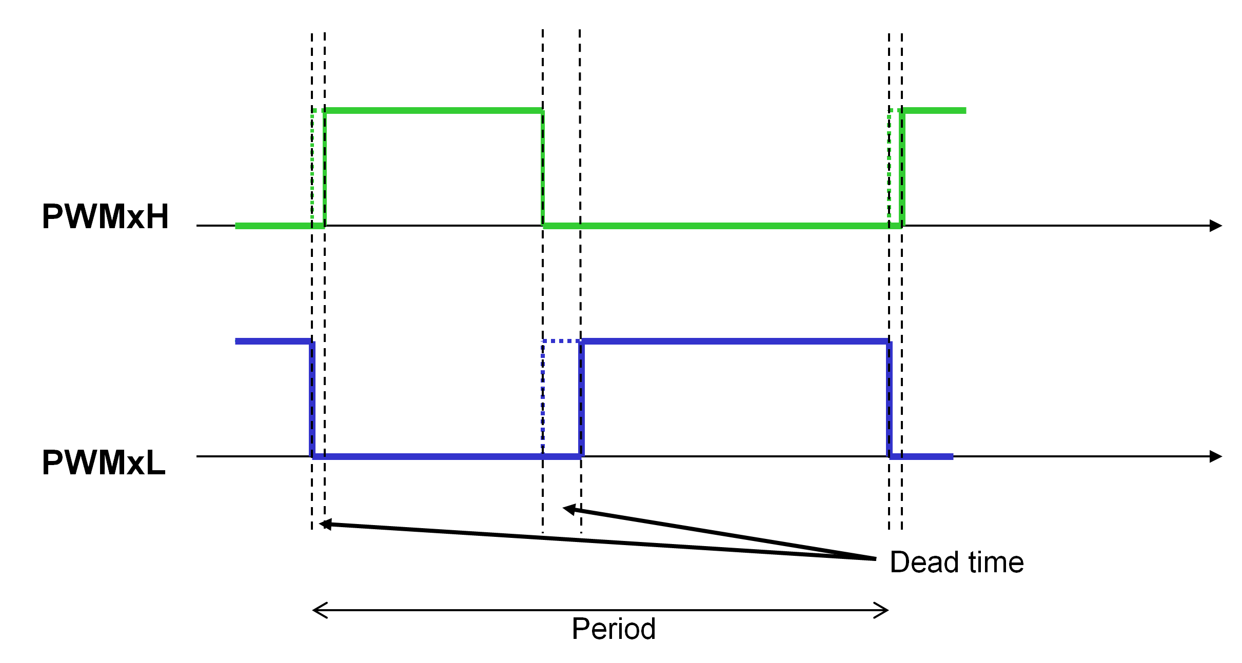
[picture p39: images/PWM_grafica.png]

>**NOTA: imagen referenciada de: https://microchipdeveloper.com/pwr3101:pwm-operations**

En esta gráfica se puede apreciar el ciclo completo del PWM, que se compone en PWMH y PWML, además se visualiza el "tiempo muerto" que ocurre inmediatamente antes del cambio de estado de los transistores con el fin de proteger los componentes.

Para más información sobre el PWM se puede buscar en [documentación PWM](http://ww1.microchip.com/downloads/en/DeviceDoc/60001393A.pdf).

# Hardware

A continuación se representa la conexión del motor con encoder realizada en la tarjeta a través de la siguiente imagen.

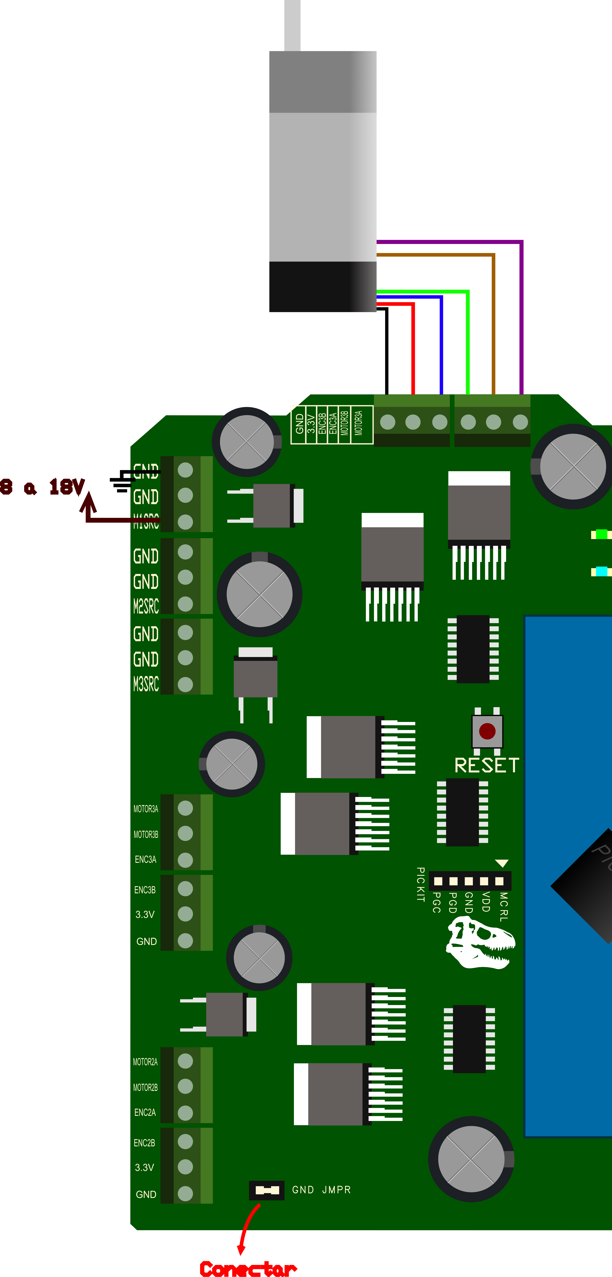
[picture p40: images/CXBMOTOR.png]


Las conexiones para este experimento son ilustradas en la imagen superior con distintos cables, los cuales representan lo siguiente.

+ ***Cable Negro***: Conexión a tierra
+ ***Cable Rojo***: Alimentación (3.3V)
+ ***Cable Azul***: Entrada B de encoder de cuadratura
+ ***Cable Verde***: Entrada A de encoder de cuadratura
+ ***Cable Café***: Entrada B de motor 
+ ***Cable Morado***: Entrada A de motor

Para invertir el sentido de giro con relación a la lectura del encoder se pueden intercambiar los cables representados en el color **Café** y **Morado**, ya que son las conexiones de salida de los puente H de la tarjeta electrónica, o tambien se pueden invertir los cables **Azul** y **Verde**

M1SRC ubicado en la bornera de la zona superior izquierda (alimentación puente) de la [tarjeta electrónica](https://github.com/CXBRexDevs/Codigos-ejemplo-CXB/blob/015453cbffbb8909efc1b8809f53027d9adc56b4/images/BASEDibujoCXBareas.png) es el voltaje de alimentación para los puente H, donde se recomienda un voltaje entre 8 y 18 voltios, también se debe conectar la conexión a tierra para el componente en la bornera.

GND JMPR ubicado en la zona inferior izquierda de la [tarjeta electrónica](https://github.com/CXBRexDevs/Codigos-ejemplo-CXB/blob/015453cbffbb8909efc1b8809f53027d9adc56b4/images/BASEDibujoCXBareas.png) es una terminal para un jumper que se puede conectar para compartir la tierra del medio puente H con la tierra del microcontrolador en la tarjeta.

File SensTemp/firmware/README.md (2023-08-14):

# Configuración de conexiones y ejemplo básico

Para medir la temperatura deberá escoger una termocupla, el chip integrado "MAX31855" es compatible con termopares de tipo K-, J-, N-, T-, S-, R-, o E- y cuenta con una resolución de hasta 0.25°C y una precición de &plusmn;2°C, el rango de temperatura depende del termopar elegido, para mas información puede revisar las [caracteristicas térmicas](https://www.analog.com/media/en/technical-documentation/data-sheets/max31855.pdf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) en el datasheet del integrado.

La información que transmite el conversor cuenta con tres datos, temperatura interna de la unión fría del termopar, temperatura externa del termopar y detección de errores. El ejemplo descrito en este repositorio hace uso únicamente de la detección de errores y lectura de la temperatura externa, estas corresponden a las funciones ``TermoparReady`` y ``TermoparC`` respectivamente. La forma en la que la información es entregada se puede observar en la siguiente [tabla](https://www.analog.com/media/en/technical-documentation/data-sheets/max31855.pdf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):



> **Nota:** Es importante que el usuario esté al tanto que independientemente del sensor que escoja, este contará con una no-linealidad intrinseca, aunque el chip ofrezca acoplamiento para su lectura, es posible que las medidas tengan una desviación y esta debe ser tenida en cuenta y corregida de acuerdo a las necesidades del experimento.

Conecte el termopar el terminal SENS TEMP, teniendo en cuenta la polaridad de su sensor.

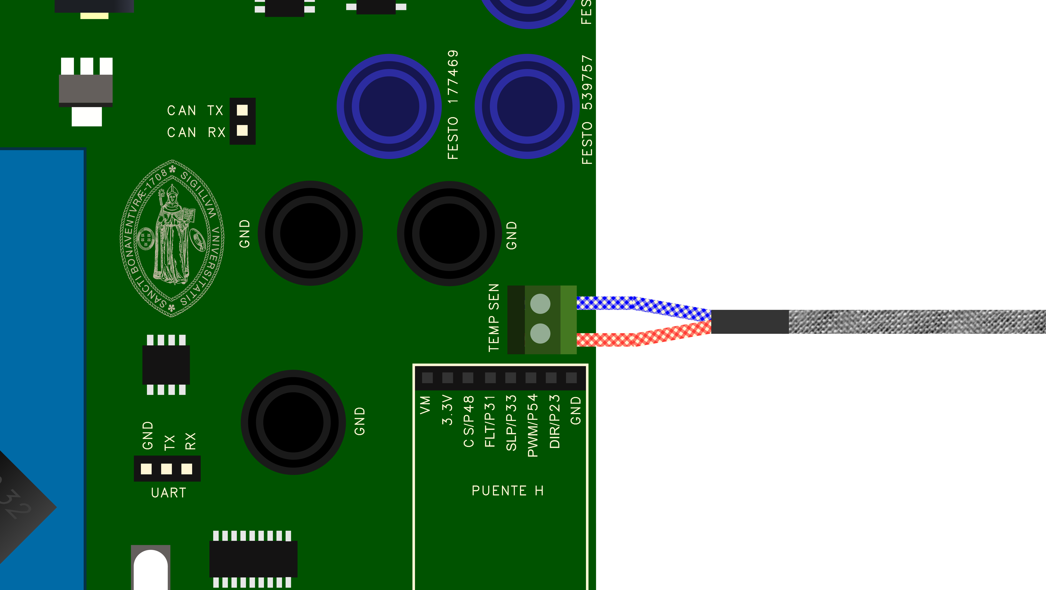
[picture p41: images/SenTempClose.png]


> **Nota:** Si la medida de temperatura resulta muy sensible al ruido, puede conectar (o soldar) un capacitor de entre 10nF a 100nF a la bornera del termopar para mitigar lo.

Conecte el conversor de información serial TTL a USB a su respectivo terminal y luego conectelo a su PC, abra su terminal serial predilecto (Ejemplo: realTerm), configure el terminal a ```9600 bauds``` , ```1 Stop bit``` y ```8-bitdata, no parity```.

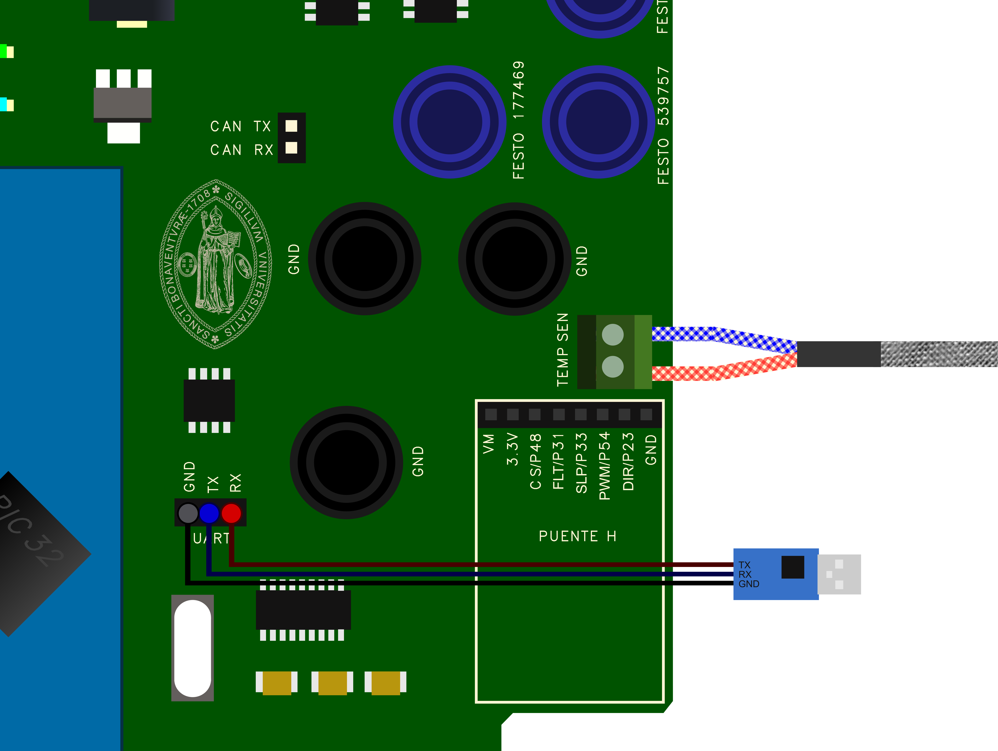
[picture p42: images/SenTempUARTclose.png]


Conecte alimentación, encienda el switch y programe el microcontrolador con el ejemplo provisto en este repositorio ([SensTemp](https://github.com/CXBRexDevs/Codigos-ejemplo-CXB/tree/main/SensTemp)), podrá ver en el terminal serial el siguiente menú:

```
    #############################
    #                           #
    #   Lectura de termocupla   #
    #                           #
    #############################
    25.000°C
```

Compare las medidas con las de un termómetro externo para asegurarse que su termopar esta conctado correctamente y que la conversión se está ejecutando adecuadamente. Adicionalmente podrá intercambiar el algoritmo principal en el programa "[main.c](https://github.com/CXBRexDevs/Codigos-ejemplo-CXB/blob/main/SensTemp/firmware/src/main.c)" con el algoritmo "[ShiftedBits.c](https://github.com/CXBRexDevs/Codigos-ejemplo-CXB/blob/main/SensTemp/firmware/ShiftedBits.c)", para comprobar que los datos entregados por el chip MAX31855, concuerdan con la [tabla](https://www.analog.com/media/en/technical-documentation/data-sheets/max31855.pdf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) de registro de datos vista previamente.

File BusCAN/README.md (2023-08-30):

# Hardware

Para utilizar la comunicación del protocolo CAN es necesaria la implementación de un transceptor "TJA1050", en las siguientes imágenes se ilustra el circuito y las funciones del integrado.



El esquema de conexión se ilustra en la siguiente figura, donde el pin #5 (Vref) no se utiliza para este ejemplo.



Conecte uno de los transceptores a los terminales "CAN_TX" y "CAN_RX", así como se muestra en la siguiente figura.



Energice y programe el microcontrolador, conecte los terminales CANHI y CANLO a otro dispositivo CAN para empezar a transmitir o recibir mensajes como se muestra en la siguiente figura.



Para comunicar el microcontrolador con otro dispositivo se deben utilizar dos transceptores, uno para las terminales CANH y CANL de la tarjeta, se recomienda utilizar el mencionado anteriormente 'TJA1050' para la conexion de la tarjeta, y otro transceptor para el otro dispositivo de comunicación externo, cabe aclarar que un dispositivo CAN puede disponer de un transceptor al igual que un módulo para comunicación integrados, por lo que se pueden usar para que cumpla el papel de los dos componentes (transceptor y módulo de comunicación). La conexión se debe realizar como se observa en la imagen superior.

Para encontrar una mayor información sobre el módulo CAN puede buscar en la [Documentación de módulo CAN](https://ww1.microchip.com/downloads/en/DeviceDoc/61154C.pdf)

# Software

Descargue y abra este proyecto en MPLAB, al concluir la progrmación y adecuada conexión del puerto serial, el terminal serial presentará un menú al usuario, brindándole la opción de presionar el número 1 para transmitir información, o en su lugar presionar el número 2 para recibir información, si se produce un error o inconveniente durante la comunicación al igual que si el usuario provee una entrada incorrecta en el menú el programa notificará lo ocurrido y retornará al menú para solicitar nuevamente una respuesta del usuario para transmitir o recibir información. Este ejemplo fue adaptado de "[can normal operation interrupt timestamp](https://github.com/Microchip-MPLAB-Harmony/csp_apps_pic32mx/tree/master/apps/can/can_normal_operation_interrupt_timestamp)" y fué adaptado para ser compatible con CXB Rex usando un PIC32MK1024MCF064.

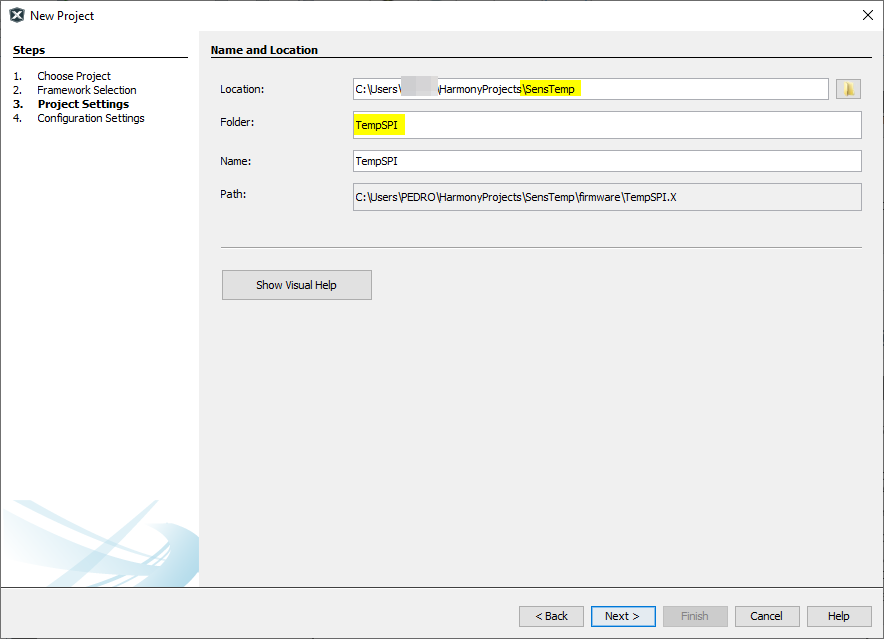
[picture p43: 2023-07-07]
images/SPI2.png

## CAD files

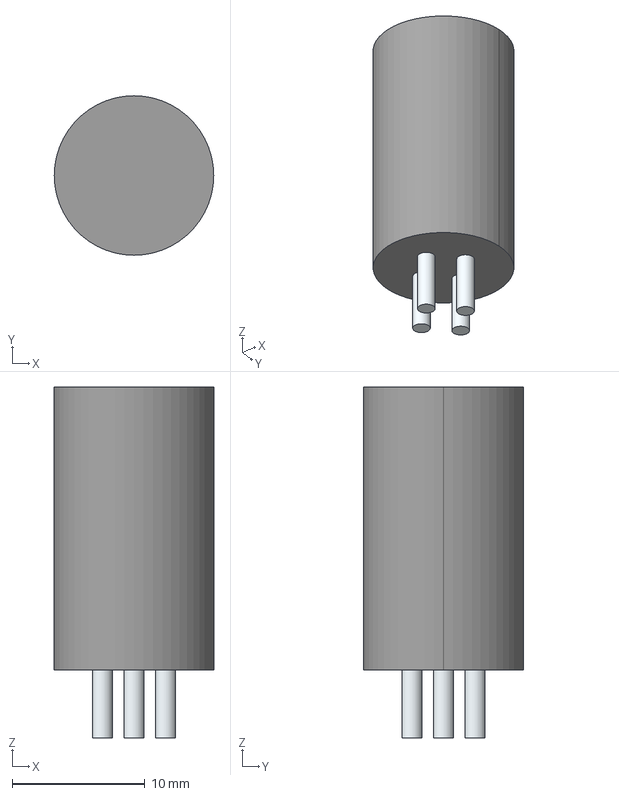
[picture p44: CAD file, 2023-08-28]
KiCAD Files/Esquema CBX Rex FINAL 26_08_23/LIB_CT3151V1-0/CT3151V1-0/3D/CT3151V1-0.stp
12.0 x 12.0 x 26.4 mm
Leads x 4

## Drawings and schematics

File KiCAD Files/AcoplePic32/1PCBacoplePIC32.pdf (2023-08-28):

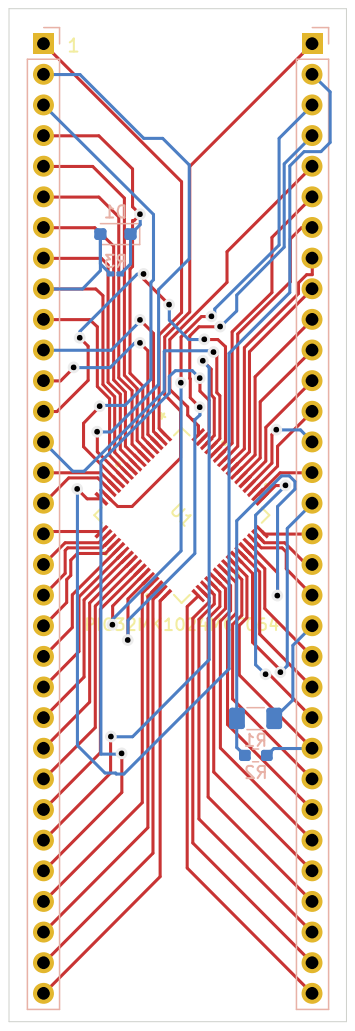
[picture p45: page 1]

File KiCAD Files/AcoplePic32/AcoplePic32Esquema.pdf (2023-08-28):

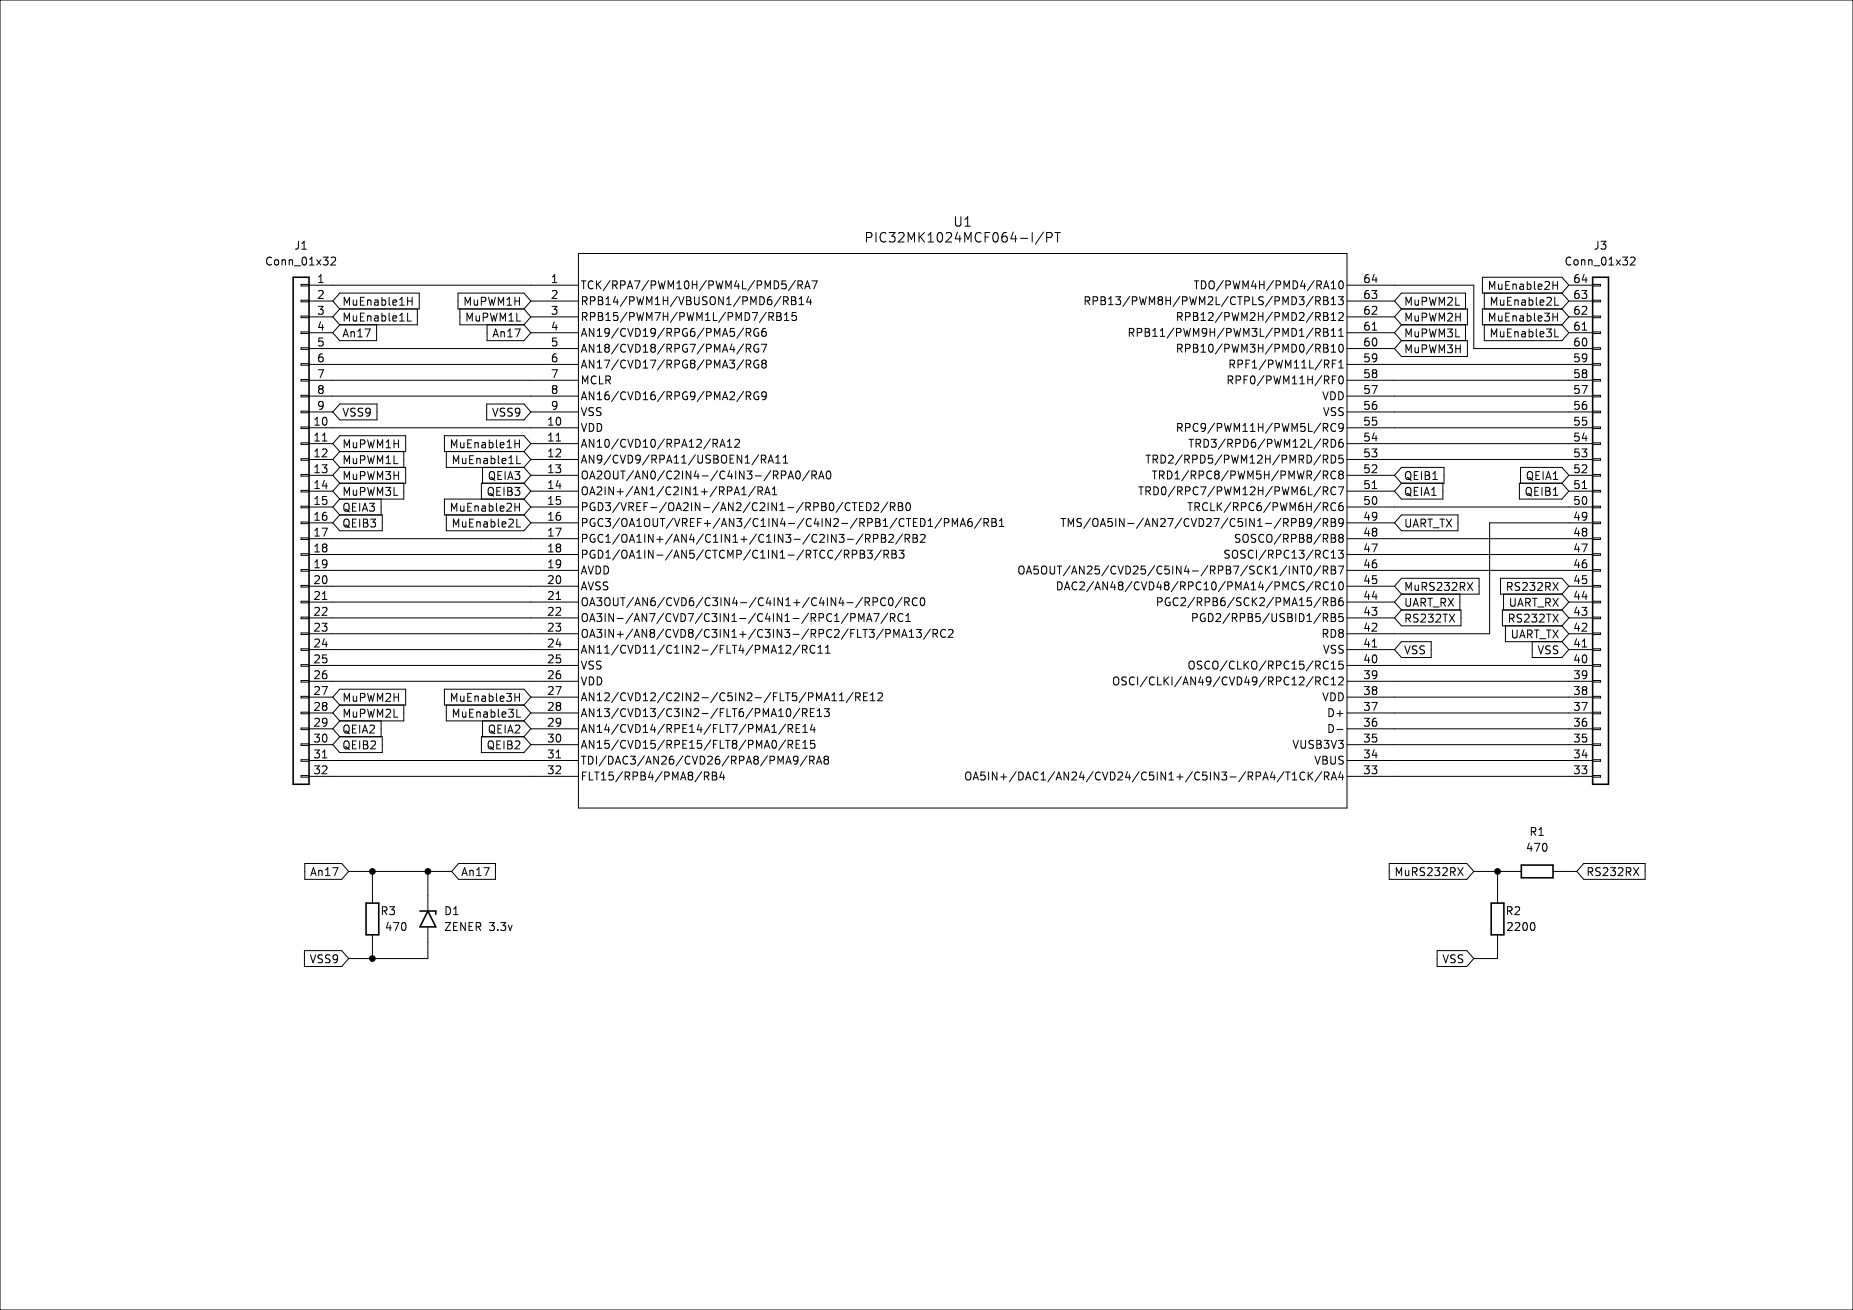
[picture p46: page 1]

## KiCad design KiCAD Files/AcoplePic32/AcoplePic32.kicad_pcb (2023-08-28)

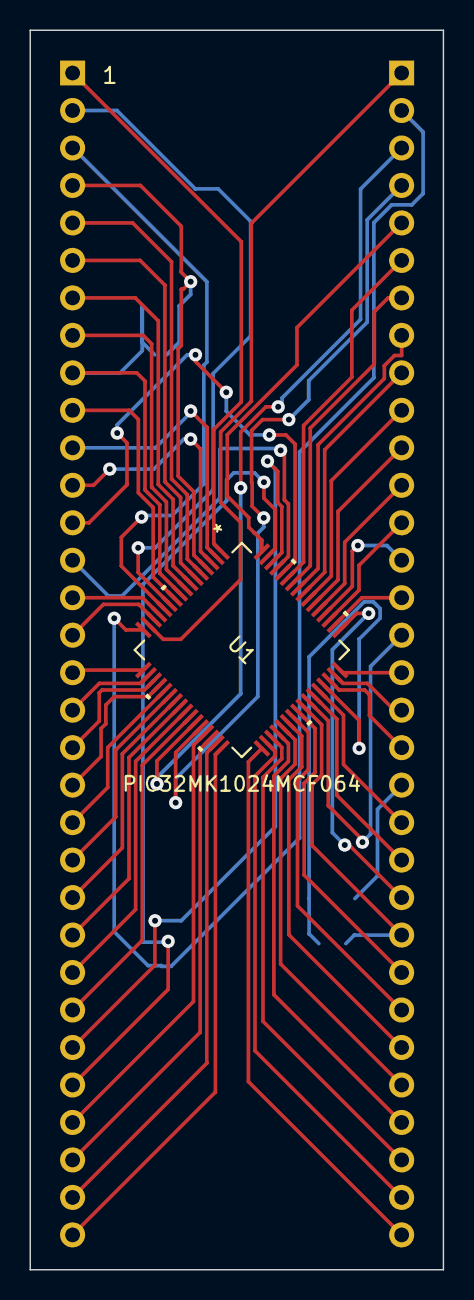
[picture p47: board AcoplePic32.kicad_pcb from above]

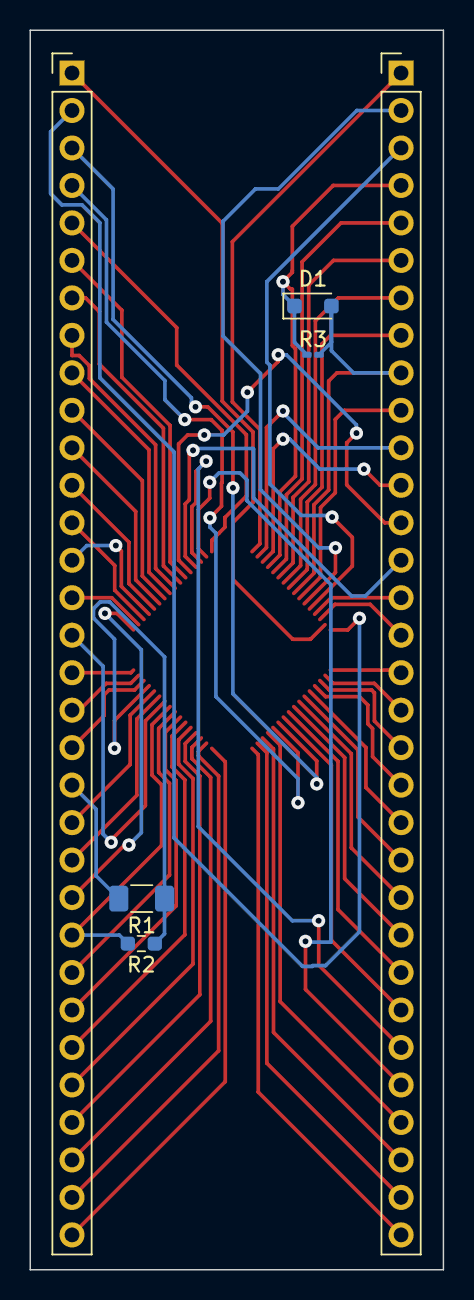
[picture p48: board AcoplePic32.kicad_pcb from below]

Board: 2 copper layers, 28.0 x 84.0 mm, 7 parts (6 on the bottom side), 65 nets.

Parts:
D1: ZENER 3.3v; D_SOD-323_HandSoldering
J1, J3: Conn_01x32; PinHeader_1x32_P2.54mm_Vertical
R1: 470; R_1206_3216Metric_Pad1.30x1.75mm_HandSolder
R2: 2200; R_0603_1608Metric_Pad0.98x0.95mm_HandSolder
R3: 100; R_0201_0603Metric_Pad0.64x0.40mm_HandSolder
U1: PIC32MK1024MCF064; TQFP64_PT_MCH

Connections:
An17: D1.1 (A1), J1.4, R3.1, U1.4 (AN19/CVD19/RPG6/PMA5/RG6)
MuEnable1H: J1.2, U1.11 (AN10/CVD10/RPA12/RA12)
MuEnable1L: J1.3, U1.12 (AN9/CVD9/RPA11/USBOEN1/RA11)
MuEnable2H: J3.64 (Pin_1), U1.15 (PGD3/VREF-/OA2IN-/AN2/C2IN1-/RPB0/CTED2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)
MuEnable2L: J3.63 (Pin_2), U1.16 (PGC3/OA1OUT/VREF+/AN3/C1IN4-/C4IN2-/RPB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)
MuEnable3H: J3.62 (Pin_3), U1.27 (AN12/CVD12/C2IN2-/C5IN2-/FLT5/PMA11/RE12)
MuEnable3L: J3.61 (Pin_4), U1.28 (AN13/CVD13/C3IN2-/FLT6/PMA10/RE13)
MuPWM1H: J1.11, U1.2 (RPB14/PWM1H/VBUSON1/PMD6/RB14)
MuPWM1L: J1.12, U1.3 (RPB15/PWM7H/PWM1L/PMD7/RB15)
MuPWM2H: J1.27, U1.62 (RPB12/PWM2H/PMD2/RB12)
MuPWM2L: J1.28, U1.63 (RPB13/PWM8H/PWM2L/CTPLS/PMD3/RB13)
MuPWM3H: J1.13, U1.60 (RPB10/PWM3H/PMD0/RB10)
MuPWM3L: J1.14, U1.61 (RPB11/PWM9H/PWM3L/PMD1/RB11)
MuRS232RX: R1.1, R2.1, U1.45 (DAC2/AN48/CVD48/RPC10/PMA14/PMCS/RC10)
unnamed: J1.1, U1.1 (TCK/RPA7/PWM10H/PWM4L/PMD5/RA7)
unnamed: J1.5, U1.5 (AN18/CVD18/RPG7/PMA4/RG7)
unnamed: J1.6, U1.6 (AN17/CVD17/RPG8/PMA3/RG8)
unnamed: J1.7, U1.7 (MCLR)
unnamed: J1.8, U1.8 (AN16/CVD16/RPG9/PMA2/RG9)
unnamed: J1.10, U1.10 (VDD)
unnamed: J1.17, U1.17 (PGC1/OA1IN+/AN4/C1IN1+/C1IN3-/C2IN3-/RP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)
unnamed: J1.18, U1.18 (PGD1/OA1IN-/AN5/CTCMP/C1IN1-/RTCC/RPB3/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)
unnamed: J1.19, U1.19 (AVDD)
unnamed: J1.20, U1.20 (AVSS)
unnamed: J1.21, U1.21 (OA3OUT/AN6/CVD6/C3IN4-/C4IN1+/C4IN4-/RP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)
unnamed: J1.22, U1.22 (OA3IN-/AN7/CVD7/C3IN1-/C4IN1-/RPC1/PMA7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)
unnamed: J1.23, U1.23 (OA3IN+/AN8/CVD8/C3IN1+/C3IN3-/RPC2/FLT3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)
unnamed: J1.24, U1.24 (AN11/CVD11/C1IN2-/FLT4/PMA12/RC11)
unnamed: J1.25, U1.25 (VSS)
unnamed: J1.26, U1.26 (VDD)
unnamed: J1.31, U1.31 (TDI/DAC3/AN26/CVD26/RPA8/PMA9/RA8)
unnamed: J1.32, U1.32 (FLT15/RPB4/PMA8/RB4)
unnamed: J3.60 (Pin_5), U1.64 (TDO/PWM4H/PMD4/RA10)
unnamed: J3.59 (Pin_6), U1.59 (RPF1/PWM11L/RF1)
unnamed: J3.58 (Pin_7), U1.58 (RPF0/PWM11H/RF0)
unnamed: J3.57 (Pin_8), U1.57 (VDD)
unnamed: J3.56 (Pin_9), U1.56 (VSS)
unnamed: J3.55 (Pin_10), U1.55 (RPC9/PWM11H/PWM5L/RC9)
unnamed: J3.54 (Pin_11), U1.54 (TRD3/RPD6/PWM12L/RD6)
unnamed: J3.53 (Pin_12), U1.53 (TRD2/RPD5/PWM12H/PMRD/RD5)
unnamed: J3.50 (Pin_15), U1.50 (TRCLK/RPC6/PWM6H/RC6)
unnamed: J3.49 (Pin_16), U1.42 (RD8)
unnamed: J3.48 (Pin_17), U1.48 (SOSCO/RPB8/RB8)
unnamed: J3.47 (Pin_18), U1.47 (SOSCI/RPC13/RC13)
unnamed: J3.46 (Pin_19), U1.46 (OA5OUT/AN25/CVD25/C5IN4-/RPB7/SCK1/INT0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)
unnamed: J3.40 (Pin_25), U1.40 (OSCO/CLKO/RPC15/RC15)
unnamed: J3.39 (Pin_26), U1.39 (OSCI/CLKI/AN49/CVD49/RPC12/RC12)
unnamed: J3.38 (Pin_27), U1.38 (VDD)
unnamed: J3.37 (Pin_28), U1.37 (D+)
unnamed: J3.36 (Pin_29), U1.36 (D-)
unnamed: J3.35 (Pin_30), U1.35 (VUSB3V3)
unnamed: J3.34 (Pin_31), U1.34 (VBUS)
unnamed: J3.33 (Pin_32), U1.33 (OA5IN+/DAC1/AN24/CVD24/C5IN1+/C5IN3-/RP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)
QEIA1: J3.52 (Pin_13), U1.51 (TRD0/RPC7/PWM12H/PWM6L/RC7)
QEIA2: J1.29, U1.29 (AN14/CVD14/RPE14/FLT7/PMA1/RE14)
QEIA3: J1.15, U1.13 (OA2OUT/AN0/C2IN4-/C4IN3-/RPA0/RA0)
QEIB1: J3.51 (Pin_14), U1.52 (TRD1/RPC8/PWM5H/PMWR/RC8)
QEIB2: J1.30, U1.30 (AN15/CVD15/RPE15/FLT8/PMA0/RE15)
QEIB3: J1.16, U1.14 (OA2IN+/AN1/C2IN1+/RPA1/RA1)
RS232RX: J3.45 (Pin_20), R1.2
RS232TX: J3.43 (Pin_22), U1.43 (PGD2/RPB5/USBID1/RB5)
UART_RX: J3.44 (Pin_21), U1.44 (PGC2/RPB6/SCK2/PMA15/RB6)
UART_TX: J3.42 (Pin_23), U1.49 (TMS/OA5IN-/AN27/CVD27/C5IN1-/RPB9/RB9)
VSS: J3.41 (Pin_24), R2.2, U1.41 (VSS)
VSS9: D1.2 (A2), J1.9, R3.2, U1.9 (VSS)

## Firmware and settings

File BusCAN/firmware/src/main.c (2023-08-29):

/*******************************************************************************
  Main Source File

  Company:
    Microchip Technology Inc.

  File Name:
    main.c

  Summary:
    This file contains the "main" function for a project.

  Description:
    This file contains the "main" function for a project.  The
    "main" function calls the "SYS_Initialize" function to initialize the state
    machines of all modules in the system
 *******************************************************************************/

/*******************************************************************************
* Copyright (C) 2019 Microchip Technology Inc. and its subsidiaries.
*
* Subject to your compliance with these terms, you may use Microchip software
* and any derivatives exclusively with Microchip products. It is your
* responsibility to comply with third party license terms applicable to your
* use of third party software (including open source software) that may
* accompany Microchip software.
*
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
* IN NO EVENT WILL MICROCHIP BE LIABLE FOR ANY INDIRECT, SPECIAL, PUNITIVE,
* INCIDENTAL OR CONSEQUENTIAL LOSS, DAMAGE, COST OR EXPENSE OF ANY KIND
* WHATSOEVER RELATED TO THE SOFTWARE, HOWEVER CAUSED, EVEN IF MICROCHIP HAS
* BEEN ADVISED OF THE POSSIBILITY OR THE DAMAGES ARE FORESEEABLE. TO THE
* FULLEST EXTENT ALLOWED BY LAW, MICROCHIP'S TOTAL LIABILITY ON ALL CLAIMS IN
* ANY WAY RELATED TO THIS SOFTWARE WILL NOT EXCEED THE AMOUNT OF FEES, IF ANY,
* THAT YOU HAVE PAID DIRECTLY TO MICROCHIP FOR THIS SOFTWARE.
*******************************************************************************/

// *****************************************************************************
// *****************************************************************************
// Section: Included Files
// *****************************************************************************
// *****************************************************************************

#include <stddef.h>                     // Defines NULL
#include <stdbool.h>                    // Defines true
#include <stdlib.h>                     // Defines EXIT_FAILURE
#include <stdarg.h>
#include "definitions.h"                // SYS function prototypes

/* Application's state machine enum */
typedef enum
{
    APP_STATE_CAN_RECEIVE,
    APP_STATE_CAN_TRANSMIT,
    APP_STATE_CAN_IDLE,
    APP_STATE_CAN_USER_INPUT,
    APP_STATE_CAN_XFER_SUCCESSFUL,
    APP_STATE_CAN_XFER_ERROR
} APP_STATES;

/* set format attribute for the vararg function */
void PrintFormattedData (const char * format, ...) __attribute__ ((format (printf, 1, 2)));

/* Variable to save application state */
static APP_STATES state = APP_STATE_CAN_USER_INPUT;
/* Variable to save Tx/Rx transfer status and context */
static uint32_t status = 0;
static uint32_t xferContext = 0;
/* Variable to save Tx/Rx message */
static uint32_t messageID = 0;
static uint8_t message[8];
static uint8_t messageLength = 0;
static uint8_t rx_message[8];
static uint32_t rx_messageID = 0;
static uint8_t rx_messageLength = 0;
static uint16_t timestamp = 0;
static CAN_MSG_RX_ATTRIBUTE msgAttr = CAN_MSG_RX_DATA_FRAME;

// *****************************************************************************
// *****************************************************************************
// Section: Local functions
// *****************************************************************************
// *****************************************************************************

/* This function will be called by CAN PLIB when transfer is completed */
// *****************************************************************************
/* void APP_CAN_Callback(uintptr_t context)

  Summary:
    Function called by CAN PLIB upon transfer completion

  Description:
    This function will be called by CAN PLIB when transfer is completed.
    In this function, current state of the application is obtained by context
    parameter. Based on current state of the application and CAN error
    state, next state of the application is decided.

  Remarks:
    None.
*/
void APP_CAN_Callback(uintptr_t context)
{
    xferContext = context;

    /* Check CAN Status */
    status = CAN1_ErrorGet();

    if ((status & (CAN_ERROR_TX_RX_WARNING_STATE | CAN_ERROR_RX_WARNING_STATE |
                   CAN_ERROR_TX_WARNING_STATE | CAN_ERROR_RX_BUS_PASSIVE_STATE |
                   CAN_ERROR_TX_BUS_PASSIVE_STATE | CAN_ERROR_TX_BUS_OFF_STATE)) == CAN_ERROR_NONE)
    {
        switch ((APP_STATES)context)
        {
            case APP_STATE_CAN_RECEIVE:
            case APP_STATE_CAN_TRANSMIT:
            {
                state = APP_STATE_CAN_XFER_SUCCESSFUL;
                break;
            }
            default:
                break;
        }
    }
    else
    {
        state = APP_STATE_CAN_XFER_ERROR;
    }
}

void print_menu(void)
{
    printf(" ------------------------------ \r\n");   
    printf(" Press '1' to Transmit message \r\n");
    printf(" Press '2' to Receive message \r\n");
}

void PrintFormattedData (const char * format, ...)
{
    va_list args = {0};
    va_start (args, format);
    vprintf (format, args);
    va_end (args);
}

// *****************************************************************************
// *****************************************************************************
// Section: Main Entry Point
// *****************************************************************************
// *****************************************************************************

int main ( void )
{
    uint8_t user_input = 0;
    uint8_t count = 0;

    /* Initialize all modules */
    SYS_Initialize ( NULL );

    printf(" ------------------------------ \r\n");
    printf("            CAN Demo            \r\n");
    printf(" ------------------------------ \r\n");
    
    print_menu();
    
    /* Prepare the message to send*/
    messageID = 0x469;
    messageLength = 8;
    for (count = 8; count >=1; count--)
    {
        message[count - 1] = count;
    }
    
    while ( true )
    {
//        printf("esperando");
        if (state == APP_STATE_CAN_USER_INPUT)
        {
            /* Read user input */
            UART5_Read((void *)&user_input, 1);
            
            switch (user_input)
            {
                case '1': 
                    printf(" Transmitting Message:");
                    CAN1_CallbackRegister( APP_CAN_Callback, (uintptr_t)APP_STATE_CAN_TRANSMIT, 0 );
                    state = APP_STATE_CAN_IDLE;
                    if (CAN1_MessageTransmit(messageID, messageLength, message, 0, CAN_MSG_TX_DATA_FRAME) == false)
                    {
                        printf("CAN1_MessageTransmit request has failed\r\n");
                    }             
                    break;
                case '2':
                    printf(" Waiting for message: \r\n");
                    CAN1_CallbackRegister( APP_CAN_Callback, (uintptr_t)APP_STATE_CAN_RECEIVE, 1 );
                    state = APP_STATE_CAN_IDLE;
                    memset(rx_message, 0x00, sizeof(rx_message));
                    /* Receive New Message */
                    if (CAN1_MessageReceive(&rx_messageID, &rx_messageLength, rx_message, &timestamp, 1, &msgAttr) == false)  
                    {
                        printf("CAN1_MessageReceive request has failed\r\n");
                    }
                    break;
                default:
                    printf(" Invalid Input \r\n");
                    break;
            }
        }
        /* Check the application's current state. */
        switch (state)
        {
            case APP_STATE_CAN_IDLE:
            {
                /* Application can do other task here */
                break;
            }
            case APP_STATE_CAN_XFER_SUCCESSFUL:
            {
                if ((APP_STATES)xferContext == APP_STATE_CAN_RECEIVE)
                {
                    /* Print message to Console */
                    printf(" New Message Received    \r\n");
                    uint8_t length = rx_messageLength;
                    PrintFormattedData(" Message - Timestamp : 0x%x ID : 0x%x Length : 0x%x ", (unsigned int)timestamp, (unsigned int) rx_messageID,(unsigned int) rx_messageLength);
                    printf("Message : ");
                    while(length)
                    {
                        PrintFormattedData("0x%x ", rx_message[rx_messageLength - length--]);
                    }
                    printf("\r\n");
                } 
                else if ((APP_STATES)xferContext == APP_STATE_CAN_TRANSMIT)
                {
                    printf("Success \r\n");
                }
                LED_Toggle();
                print_menu();
                state = APP_STATE_CAN_USER_INPUT;
                break;
            }
            case APP_STATE_CAN_XFER_ERROR:
            {
                if ((APP_STATES)xferContext == APP_STATE_CAN_RECEIVE)
                {
                    printf("Error in received message");
                }
                else
                {
                    printf("Failed \r\n");
                }
                print_menu();
                state = APP_STATE_CAN_USER_INPUT;
                break;
            }
            default:
                break;
        }
        
    }

    /* Execution should not come here during normal operation */

    return ( EXIT_FAILURE );
}

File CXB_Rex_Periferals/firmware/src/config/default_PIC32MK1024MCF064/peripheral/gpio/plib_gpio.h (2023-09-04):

/*******************************************************************************
  GPIO PLIB

  Company:
    Microchip Technology Inc.

  File Name:
    plib_gpio.h UUUUUUUUU

  Summary:
    GPIO PLIB Header File

  Description:
    This library provides an interface to control and interact with Parallel
    Input/Output controller (GPIO) module.

*******************************************************************************/

/*******************************************************************************
* Copyright (C) 2019 Microchip Technology Inc. and its subsidiaries.
*
* Subject to your compliance with these terms, you may use Microchip software
* and any derivatives exclusively with Microchip products. It is your
* responsibility to comply with third party license terms applicable to your
* use of third party software (including open source software) that may
* accompany Microchip software.
*
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
* IN NO EVENT WILL MICROCHIP BE LIABLE FOR ANY INDIRECT, SPECIAL, PUNITIVE,
* INCIDENTAL OR CONSEQUENTIAL LOSS, DAMAGE, COST OR EXPENSE OF ANY KIND
* WHATSOEVER RELATED TO THE SOFTWARE, HOWEVER CAUSED, EVEN IF MICROCHIP HAS
* BEEN ADVISED OF THE POSSIBILITY OR THE DAMAGES ARE FORESEEABLE. TO THE
* FULLEST EXTENT ALLOWED BY LAW, MICROCHIP'S TOTAL LIABILITY ON ALL CLAIMS IN
* ANY WAY RELATED TO THIS SOFTWARE WILL NOT EXCEED THE AMOUNT OF FEES, IF ANY,
* THAT YOU HAVE PAID DIRECTLY TO MICROCHIP FOR THIS SOFTWARE.
*******************************************************************************/

#ifndef PLIB_GPIO_H
#define PLIB_GPIO_H

#include <device.h>
#include <stdint.h>
#include <stdbool.h>
#include <stddef.h>

// DOM-IGNORE-BEGIN
#ifdef __cplusplus  // Provide C++ Compatibility

    extern "C" {

#endif
// DOM-IGNORE-END

// *****************************************************************************
// *****************************************************************************
// Section: Data types and constants
// *****************************************************************************
// *****************************************************************************


/*** Macros for PWM1H pin ***/
#define PWM1H_Get()               ((PORTB >> 14) & 0x1U)
#define PWM1H_PIN                  GPIO_PIN_RB14

/*** Macros for PWM1L pin ***/
#define PWM1L_Get()               ((PORTB >> 15) & 0x1U)
#define PWM1L_PIN                  GPIO_PIN_RB15

/*** Macros for FST_178577 pin ***/
#define FST_178577_Get()               ((PORTG >> 6) & 0x1U)
#define FST_178577_PIN                  GPIO_PIN_RG6

/*** Macros for FST_539757 pin ***/
#define FST_539757_Get()               ((PORTG >> 7) & 0x1U)
#define FST_539757_PIN                  GPIO_PIN_RG7

/*** Macros for FST_177469 pin ***/
#define FST_177469_Get()               ((PORTG >> 8) & 0x1U)
#define FST_177469_PIN                  GPIO_PIN_RG8

/*** Macros for ISH1 pin ***/
#define ISH1_Get()               ((PORTG >> 9) & 0x1U)
#define ISH1_PIN                  GPIO_PIN_RG9

/*** Macros for ENABLEH1 pin ***/
#define ENABLEH1_Set()               (LATASET = (1U<<12))
#define ENABLEH1_Clear()             (LATACLR = (1U<<12))
#define ENABLEH1_Toggle()            (LATAINV= (1U<<12))
#define ENABLEH1_OutputEnable()      (TRISACLR = (1U<<12))
#define ENABLEH1_InputEnable()       (TRISASET = (1U<<12))
#define ENABLEH1_Get()               ((PORTA >> 12) & 0x1U)
#define ENABLEH1_PIN                  GPIO_PIN_RA12

/*** Macros for ENABLEL1 pin ***/
#define ENABLEL1_Set()               (LATASET = (1U<<11))
#define ENABLEL1_Clear()             (LATACLR = (1U<<11))
#define ENABLEL1_Toggle()            (LATAINV= (1U<<11))
#define ENABLEL1_OutputEnable()      (TRISACLR = (1U<<11))
#define ENABLEL1_InputEnable()       (TRISASET = (1U<<11))
#define ENABLEL1_Get()               ((PORTA >> 11) & 0x1U)
#define ENABLEL1_PIN                  GPIO_PIN_RA11

/*** Macros for SO pin ***/
#define SO_Get()               ((PORTB >> 4) & 0x1U)
#define SO_PIN                  GPIO_PIN_RB4

/*** Macros for UART_RS232_TX pin ***/
#define UART_RS232_TX_Get()               ((PORTB >> 5) & 0x1U)
#define UART_RS232_TX_PIN                  GPIO_PIN_RB5

/*** Macros for UART_USB_RX pin ***/
#define UART_USB_RX_Get()               ((PORTB >> 6) & 0x1U)
#define UART_USB_RX_PIN                  GPIO_PIN_RB6

/*** Macros for UART_RS232_RX pin ***/
#define UART_RS232_RX_Get()               ((PORTC >> 10) & 0x1U)
#define UART_RS232_RX_PIN                  GPIO_PIN_RC10

/*** Macros for SCK pin ***/
#define SCK_Get()               ((PORTB >> 7) & 0x1U)
#define SCK_PIN                  GPIO_PIN_RB7

/*** Macros for UART_USB_TX pin ***/
#define UART_USB_TX_Get()               ((PORTB >> 9) & 0x1U)
#define UART_USB_TX_PIN                  GPIO_PIN_RB9

/*** Macros for CAN_RX pin ***/
#define CAN_RX_Get()               ((PORTF >> 0) & 0x1U)
#define CAN_RX_PIN                  GPIO_PIN_RF0
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

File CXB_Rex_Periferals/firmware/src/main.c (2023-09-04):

/*******************************************************************************
  Main Source File

  Company:
    Microchip Technology Inc.

  File Name:
    main.c

  Summary:
    This file contains the "main" function for a project.

  Description:
    This file contains the "main" function for a project.  The
    "main" function calls the "SYS_Initialize" function to initialize the state
    machines of all modules in the system
 *******************************************************************************/

// *****************************************************************************
// *****************************************************************************
// Section: Included Files
// *****************************************************************************
// *****************************************************************************

#include <stddef.h>                     // Defines NULL
#include <stdbool.h>                    // Defines true
#include <stdlib.h>                     // Defines EXIT_FAILURE
#include "definitions.h"                // SYS function prototypes
#include <time.h>
#include <math.h>

uint8_t user_input;

int ctrl=1500;
float conversion=0;
char text[317]="";
float timee=0;
uint32_t cont = 0;
int objetivo = 0;
uint16_t AdcRead = 0;
uint16_t PWM = 0;

char dataRead[16] = "";
char dataBin[35];
int buf;
char dataOk;
float DataInt;
float DataExt;
uint32_t recivedData;
uint16_t result;

/* Application's state machine enum */
typedef enum
{
    APP_STATE_CAN_RECEIVE,
    APP_STATE_CAN_TRANSMIT,
    APP_STATE_CAN_IDLE,
    APP_STATE_CAN_USER_INPUT,
    APP_STATE_CAN_XFER_SUCCESSFUL,
    APP_STATE_CAN_XFER_ERROR
} APP_STATES;

static uint32_t messageID = 0;
static uint8_t message[8];
static uint8_t messageLength = 0;
static APP_STATES state = APP_STATE_CAN_USER_INPUT;
/* Variable to save Tx/Rx transfer status and context */
static uint32_t status = 0;
static uint32_t xferContext = 0;

void TIMER1_InterruptSvcRoutine(uint32_t status, uintptr_t context)
{
    timee=timee+pow(10,-2);
}
bool TermoparReady(uint32_t value) //
{    
    //Leectura de errores
    switch(value & 0x7){
        case 0b001:
            printf("No se detecta un termopar \n");
            return false;
            break;
        case 0b010:
            printf("Termopar en corto circuito con tierra \n");
            return false;
            break;
        case 0b100:
            printf("Termopar en corto circuito con VCC \n");
            return false;
            break;
        default:
            return true;
    }
    //Lectura error de SCV, SCG o OC
    if((value & 0x10000) == 0x10000){printf("error de SCV, SCG o OC \n");
        return false;
    }else{return true;}      
}

void TermoparInt(int32_t v, float *internal)
{
    // ignore bottom 4 bits - they're just thermocouple data
    v >>= 4; 
    
    // pull the bottom 11 bits off
    *internal =(float)(v & 0x7FF);
    // check sign bit!
    if (v & 0x800) {
      // Convert to negative value by extending sign and casting to signed type.
      int16_t tmp = 0xF800 | (v & 0x7FF);
      *internal = tmp;
    }
    *internal *= 0.0625; // LSB = 0.0625 degrees
    // Serial.print("\tInternal Temp: "); Serial.println(internal);
    
}

void TermoparC(int32_t v, float *centigrade)
{

    if (v & 0x80000000) {
      // Negative value, drop the lower 18 bits and explicitly extend sign bits.
      v = 0xFFFFC000 | ((v >> 18) & 0x00003FFF);
    } else {
      // Positive value, just drop the lower 18 bits.
      v >>= 18;
    }

    // Convert to double before applying multiplication
    double temp = (double)v;

    // LSB = 0.25 degrees C
    temp *= 0.25;

    // Assign the result to the float pointed by centigrade
    *centigrade = (float)temp;

    // Return the calculated value (optional, depending on your use case)

}
    
    
void printBinary(uint32_t value, char binaryString[]) {
    int size = sizeof(value) * 8;

    uint32_t mask = 1u << (size - 1);

    int index = 0;
    for (int i = 1; i <= size; i++) {
        binaryString[index++] = (value & mask) ? '1' : '0';
        if (i == 1 || i == 14 || i == 15 || i == 16 || i == 17  || i == 28 || i == 29) {
            binaryString[index++] = ' ';
        }
        if (i == 12 || i == 24 ) {
            binaryString[index++] = '.';
        }
        mask >>= 1;
    }

    binaryString[index] = '\0';
}

void print_menu(void)
{
    printf(" ----------------------------------------------------------- \r\n");   
    printf(" Presione '1' para probar motores y lectura ADC\r\n");
    printf(" Presione '2' para probar lectura de sensor de temperatura \r\n");
    printf(" Presione '3' para probar transmitir un mensaje CAN \r\n");
}

void APP_CAN_Callback(uintptr_t context)
{
    xferContext = context;

    /* Check CAN Status */
    status = CAN1_ErrorGet();

    if ((status & (CAN_ERROR_TX_RX_WARNING_STATE | CAN_ERROR_RX_WARNING_STATE |
                   CAN_ERROR_TX_WARNING_STATE | CAN_ERROR_RX_BUS_PASSIVE_STATE |
                   CAN_ERROR_TX_BUS_PASSIVE_STATE | CAN_ERROR_TX_BUS_OFF_STATE)) == CAN_ERROR_NONE)
    {
        switch ((APP_STATES)context)
        {
            case APP_STATE_CAN_RECEIVE:
            case APP_STATE_CAN_TRANSMIT:
            {
                state = APP_STATE_CAN_XFER_SUCCESSFUL;
                break;
            }
            default:
                break;
        }
    }
    else
    {
        state = APP_STATE_CAN_XFER_ERROR;
    }
}

char UART6buff[100];
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

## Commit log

2023-07-05 Create Manual.md
    Manual que describe la creación de un proyecto básico, incluyendo encendido y apagado de LEDS, detección de pulsado de un botón y comunicación serial.
2023-07-07 Update and rename Sensor de temperatura.md to README.md
